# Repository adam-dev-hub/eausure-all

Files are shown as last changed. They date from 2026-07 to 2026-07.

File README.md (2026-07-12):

<div align="center">

Logo officiel EauSûre

<br/>







</div>

# EauSûre
Écosystème IoT de surveillance intelligente de la qualité de l'eau s'articule autour de trois composantes principales : une bouée connectée flottante chargée de la collecte des données, une passerelle LoRa développée en interne (DIY) assurant la transmission des mesures, ainsi qu'un environnement logiciel hétérogène regroupant des interfaces utilisateur, des API et une plateforme cloud pour le traitement, le stockage et la visualisation des données.

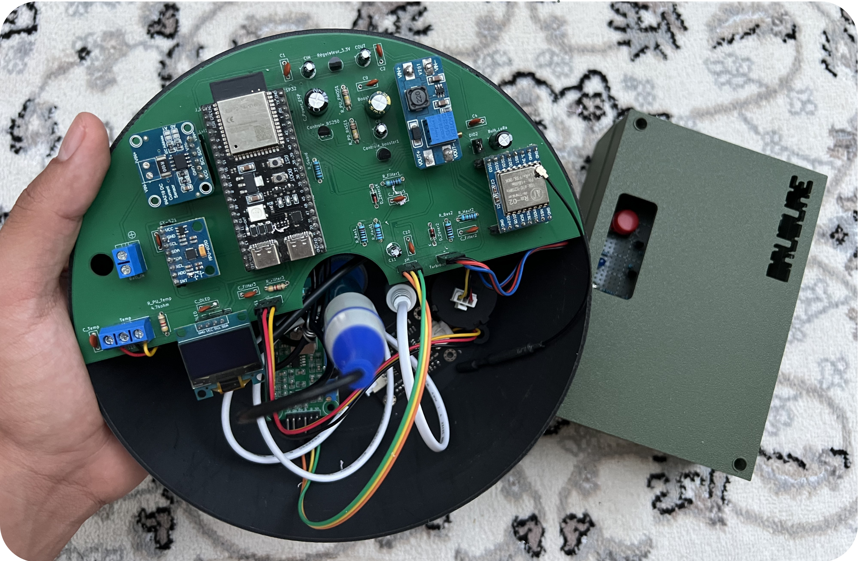
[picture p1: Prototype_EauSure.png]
Image Prototype EauSure


L'organisation regroupe les différents sous-systèmes de la solution :
- firmware embarqué du nœud de mesure et de la passerelle ;
- APIs fragmentées par responsabilité métier ;
- application mobile terrain ;
- interface web d'administration ;
- conception électronique, mécanique et modélisation système ;
- documentation technique et rapport d'ingénierie.

## Portée

EauSûre est conçu comme une plateforme complète, allant du matériel embarqué jusqu'aux interfaces de supervision.

- **Nœud de mesure** : acquisition des paramètres de qualité de l'eau, détection d'événements et communication LoRa sécurisée ;
- **Passerelle IoT** : jonction entre le terrain, le cloud, MQTT et les applications clientes ;
- **Backend fragmenté** : authentification, profil, administration, télémétrie et orchestration matérielle ;
- **Applications clientes** : usage mobile sur le terrain et supervision administrateur sur le web ;
- **Conception système** : SysML, PCB, modélisation 3D et documentation de projet.

## Dépôts principaux

- `EauSure_Firmware` : firmware du nœud de mesure et de la passerelle ;
- `EauSure_User_MobileApp` : application mobile terrain ;
- `EauSure_Admin_Dashboard_Website` : portail web d'administration ;
- `EauSure_Hardware_API` : orchestration matérielle et télémétrie ;
- `EauSure_Admin_API` : administration, pré-enregistrement et releases firmware ;
- `EauSure_Auth_API` : authentification et identité ;
- `EauSure_Profile_API` : profil utilisateur ;
- `EauSure_PCB` : conception électronique ;
- `EauSure_3D` : conception mécanique.

## Rapport

- PDF du rapport d'ingénierie : [Consulter le rapport EauSûre](https://1drv.ms/b/c/14e06c77a7dac468/IQCNwBGUbkDMTaTTdn0Hem94AVIdE5QvMWrk3accX1DUpic?e=Vb73pf)

## Architecture

- **Terrain** : nœud de mesure + passerelle ;
- **Communication** : LoRa, BLE, Wi-Fi, MQTT, HTTPS ;
- **Cloud** : APIs spécialisées, base de données, stockage firmware ;
- **Clients** : application mobile et portail web administrateur.      

## Stack

- ESP32 / FreeRTOS
- LoRa / BLE / Wi-Fi / MQTT
- Node.js / Express / TypeScript
- Next.js / React Native / Expo
- MongoDB
- KiCad / Fusion 360 / SysML / PlantUML

## Finalité

L'objectif d'EauSûre est de proposer une chaîne cohérente de surveillance de la qualité de l'eau, couvrant :
- la mesure embarquée ;
- la communication sécurisée ;
- la supervision en temps réel ;
- la maintenance et les mises à jour distantes ;
- la traçabilité technique de bout en bout.

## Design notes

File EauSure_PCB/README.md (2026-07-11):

<div align="center">

Logo officiel EauSûre

<br/>






</div>

# EauSûre Measurement Node PCB

Travail de conception PCB du nœud de mesure de la solution EauSûre.

Ce dossier contient :
- les sources KiCad du circuit principal ;
- une version inoptimisée du schéma ;
- une version simplifiée du schéma ;
- les exports visuels du schéma et du PCB ;
- un backup de fabrication avec gerbers et perçages.

## Portée

Ce dépôt documente la carte électronique du nœud de mesure EauSûre, support matériel utilisé pour :
- acquérir les paramètres physico-chimiques de l'eau : pH, TDS, turbidité et température ;
- embarquer l'unité de calcul ESP32-S3 chargée du traitement local et de la coordination des sous-ensembles ;
- intégrer le module inertiel dédié à la détection de chute et aux événements critiques ;
- assurer l'interface avec la communication LoRa sécurisée vers la passerelle ;
- supporter les phases de provisioning, d'appairage et de maintenance distante du nœud.

## Stack

- KiCad
- schématique électronique
- routage PCB
- exports SVG, PNG et PDF
- gerbers et fichiers de perçage

## Organisation du dossier

- [source](source)
  - sources KiCad principales du projet
- [exports/schematics](exports/schematics)
  - exports du schéma complet et du schéma simplifié
- [exports/board](exports/board)
  - exports visuels du PCB
- [fabrication](fabrication)
  - backup de fabrication et gerbers

## Sources principales

- [eausure-measurement-node.kicad_pcb](source/eausure-measurement-node.kicad_pcb)
- [eausure-measurement-node.kicad_pro](source/eausure-measurement-node.kicad_pro)
- [eausure-measurement-node.kicad_prl](source/eausure-measurement-node.kicad_prl)
- [eausure-measurement-node-full.kicad_sch](source/eausure-measurement-node-full.kicad_sch)
- [eausure-measurement-node-simplified.kicad_sch](source/eausure-measurement-node-simplified.kicad_sch)

## Variantes du schéma

- **Version inoptimisée** : schéma utilisé lors de la fabrication du pcb du nœud de mesure chez JLCPCB China.
- **Version simplifiée** : version la plus récente du schéma avec lisibilité ameliorée 

## Rôle du nœud de mesure dans EauSûre

Le nœud de mesure constitue le cœur embarqué de la bouée intelligente EauSûre.

Il assure notamment :
- l'acquisition périodique des mesures de qualité de l'eau ;
- le traitement local et la préparation des données avant transmission ;
- la détection de secousses anormales via le MPU6050 ;
- la communication LoRa point-à-point chiffrée avec la passerelle ;
- l'exécution de commandes distantes ;
- l'intégration dans les cycles de provisioning, d'appairage sécurisé et de mise à jour firmware.

## Aperçu du PCB

<div align="center">
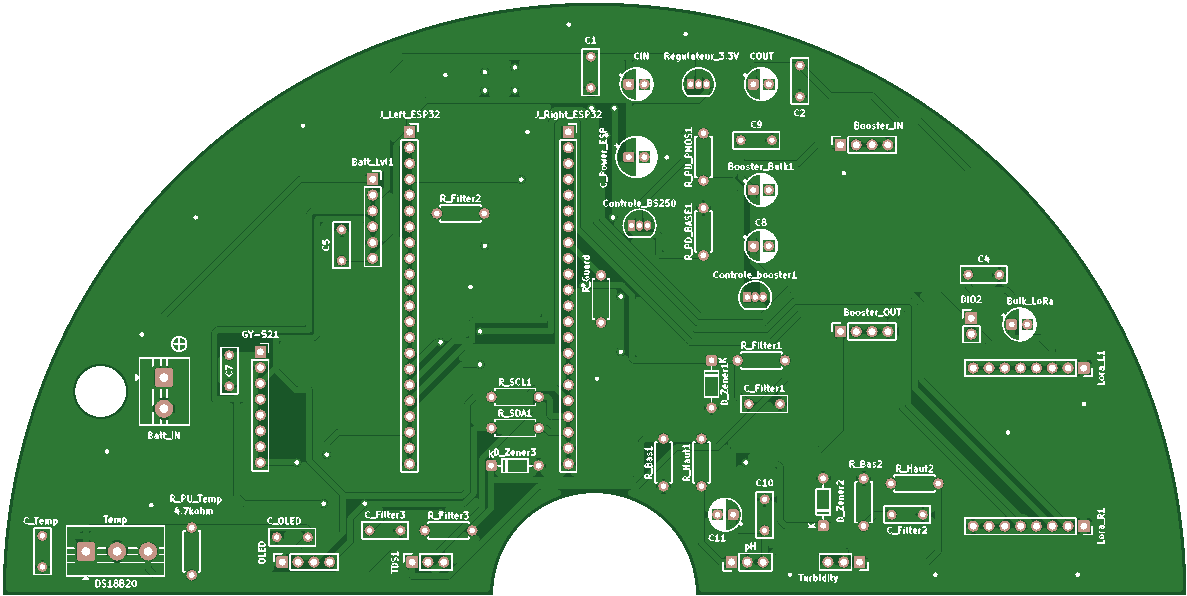
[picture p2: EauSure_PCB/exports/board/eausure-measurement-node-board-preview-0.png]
Aperçu du PCB du nœud de mesure EauSûre
  
</div>

## Fichiers de fabrication

Le dossier [fabrication](/home/adamdev/Bureau/Projet_pfe_eausure/PCB/fabrication) contient :
- les couches cuivre ;
- les masques ;
- les silkscreens ;
- les fichiers de perçage ;
- le fichier `gbrjob` ;

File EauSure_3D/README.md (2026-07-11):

<div align="center">

Logo officiel EauSûre

<br/>






</div>

# EauSûre Buoy & Gateway 3D Design

Travail de modélisation 3D de l'enveloppe mécanique de la bouée et la passerelle EauSûre.

Ce dossier contient les deux demi-coques principales du boîtier :
- la partie supérieure de la bouée ;
- la partie inférieure de la bouée ;
- la partie supérieure de la passerelle;
- la partie inférieure de la passerelle ;
- leurs sources de travail ;
- leurs exports d'impression ;
- leurs aperçus visuels.

## Portée

Le travail 3D complète la conception électronique et embarquée de la solution EauSûre.

Il couvre :
- la coque supérieure de la bouée ;
- la coque inférieure de la bouée ;
- la coque supérieure de la passerelle ;
- la coque inférieure de la passerelle ;
- la préparation des pièces pour impression ou prototypage ;
- les rendus de prévisualisation des pièces mécaniques.

## Stack

- Autodesk Fusion 360
- fichiers `3mf`
- exports `stl`
- aperçus `png`

## Organisation du dossier

- [source](source)
  - sources des pièces 3D
- [exports/stl](exports/stl)
  - exports destinés à l'impression ou à la fabrication
- [exports/previews](exports/previews)
  - aperçus visuels des pièces

## Pièces principales

**IoT Node (Buoy) :**
- [eausure-buoy-upper-shell.3mf](IoT_Node/source/eausure-buoy-upper-shell.3mf)
- [eausure-buoy-lower-shell.3mf](IoT_Node/source/eausure-buoy-lower-shell.3mf)

**Gateway Node :**
- [gateway-up-shell.stl](Gateway_Node/stl/gateway_up_shell.stl)
- [gateway-low-shell.stl](Gateway_Node/stl/gateway_low_shell.stl)

## Exports STL

**IoT Node (Buoy) :**
- [eausure-buoy-upper-shell.stl](IoT_Node/exports/stl/eausure-buoy-upper-shell.stl)
- [eausure-buoy-lower-shell.stl](IoT_Node/exports/stl/eausure-buoy-lower-shell.stl)

**Gateway Node :**
- [gateway-up-shell.stl](Gateway_Node/stl/gateway_up_shell.stl)
- [gateway-low-shell.stl](Gateway_Node/stl/gateway_low_shell.stl)

## Aperçus

**IoT Node (Buoy) :**
- [eausure-buoy-upper-shell.png](IoT_Node/exports/previews/eausure-buoy-up-shell.png)
- [eausure-buoy-lower-shell.png](IoT_Node/exports/previews/eausure-buoy-low-shell.png)

**Gateway Node :**
- [gateway-shell.png](Gateway_Node/preview/gateway_shell.png)

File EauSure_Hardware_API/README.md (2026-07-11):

<div align="center">

Logo officiel EauSûre

<br/>







</div>

# EauSûre Hardware API

API centrale de communication terrain pour l'écosystème EauSûre.

Elle est consommée par :
- `Application_Web` pour la supervision, la télémétrie, les gateways et les nœuds ;
- `Application_Mobile` pour la télémétrie, le pairing, la configuration et le provisioning ;
- `Application_Admin_API` pour le pré-enregistrement matériel ;
- `MyFreeRTOSProject` côté firmware gateway et node pour le provisioning, le pairing, les heartbeats, la télémétrie et les commandes.

## Portée

L'écosystème backend d'EauSûre repose sur une fragmentation fonctionnelle des APIs. Chaque service couvre un périmètre précis, mais l'ensemble fonctionne de manière complémentaire :
- **Hardware API** : provisioning, pairing, commandes, télémétrie et orchestration gateway/node ;
- **Admin API** : administration, pré-enregistrement et gestion des releases firmware ;
- **Auth API** : authentification, identité, jetons d'accès et OAuth ;
- **Profile API** : profil utilisateur et préférences.

Dans cette architecture, `Hardware_API` concentre la logique d'échange avec le matériel :
- **ingestion télémétrique** ;
- **provisioning gateway** ;
- **pairing node** ;
- **configuration et commandes MQTT** ;
- **état runtime des gateways et nœuds** ;
- **intégration firmware OTA/FUOTA côté commandes**.

## Vue d'ensemble

```text
                           +----------------------+
                           |   Web / Mobile App   |
                           |  JWT-authenticated   |
                           +----------+-----------+
                                      |
                                      | manage gateways, nodes,
                                      | confirm pairing
                                      v
+-------------+               +-------+--------+               +------------------+
|  IoT Node   | <-- LoRa ---> |      Gateway   | <-- HTTPS --> |       API        |
|  ESP32-S3   | <- Wifi AP -> |      ESP32     |               |  Express + TS    |
+------+------+               +---+---------+--+               +-----+--------+---+
       |                          |         |                        |        |
       | local AP during pairing  |         | MQTT commands/events   |        |
       | /identity                |         +----------------------->|        |
       | /prove                   |         |<-----------------------+        |
       | /provision               |                                           |
       |                          | telemetry/Status transmission             |
       |During Pairing Phase Only +------------------------------------------>|
       +--------------------------+------------------------------------------>|
                                                                              |
                                                               +-----------------------------+
                                                               |                             |              
                                                     +---------V---------+         +---------V---------+
                                                     |      MongoDB      |         |    MQTT Broker    |
                                                     | telemetry, nodes, |         | live data + cmds  |
                                                     | gateways, pairing |         +-------------------+
                                                     | sessions, command |
                                                     +-------------------+
```               

```text
Provisioning / Pairing
----------------------
Admin Web/App -> API: pre-register gateway and node
Gateway -> API: provision gateway to user account
Gateway -> API: confirm candidate / verify node proof
Node -> API: finalize pair-node
API -> Gateway: publish PAIRING_KEY_READY

Runtime
-------
Gateway -> Node: ACTIVATE / HEARTBEAT_REQ / MEASURE_REQ
Node -> Gateway: encrypted DATA / HEARTBEAT_ACK / ACTIVATE_OK
Gateway -> API: POST /api/sensor-data
API -> MongoDB: persist reading
API -> MQTT: publish live update
```

## Stack

- Node.js + Express
- TypeScript
- MongoDB + Mongoose
- MQTT
- JWT côté routes utilisateur
- API key côté firmware gateway

## Rôle de l'API

- reçoit les données capteurs transmises par la gateway via HTTP
- stocke la télémétrie, les signaux radio et les événements dans MongoDB
- publie la télémétrie temps réel sur MQTT pour les dashboards et les clients
- provisionne les gateways sur les comptes utilisateurs
- gère les sessions de pairing des nœuds et l'échange des clés de pairing
- expose des routes authentifiées pour la gestion des gateways et des nœuds

## Consommation de l'API

### Depuis `Application_Web`

Les pages web appellent réellement :
- `GET /api/sensor-data`
- `GET /api/sensor-data/latest`
- `GET /api/sensor-data/stats`
- `GET /api/gateways`
- `GET /api/gateways/:gatewayId/status`
- `GET /api/gateways/:gatewayId/nodes`
- `POST /api/gateways/:gatewayId/nodes/:nodeId/measure`

Le dépôt web contient aussi des routes proxy Next.js pour :
- `PUT /api/gateways/:gatewayId/config`
- `DELETE /api/gateways/:gatewayId`
- `POST /api/gateways/:gatewayId/pairing/confirm-candidate`
- `DELETE /api/gateways/:gatewayId/nodes/:nodeId`
- `PUT /api/gateways/:gatewayId/nodes/:nodeId/config`
- `POST /api/gateways/:gatewayId/firmware-update`
- `POST /api/gateways/:gatewayId/nodes/:nodeId/firmware-update`

À ce stade, je n'ai pas retrouvé d'appel direct depuis une page React vers ces proxies. Pour le web, la gestion des releases FUOTA passe surtout par `Application_Admin_API`, tandis que les commandes de déploiement matériel sont surtout consommées côté mobile.

### Depuis `Application_Mobile`

Le code consomme notamment :
- `GET /sensor-data`
- `GET /sensor-data/latest`
- `GET /sensor-data/stats`
- `GET /gateways`
- `GET /gateways/:gatewayId/nodes`
- `GET /gateways/:gatewayId/commands/:commandId`
- `POST /gateways/:gatewayId/pairing/confirm-candidate`
- `GET /gateways/:gatewayId/pairing/scan`
- `GET /gateways/:gatewayId/pairing/session/:sessionId`
- `PUT /gateways/:gatewayId/location`
- `PUT /gateways/:gatewayId/nodes/:nodeId/config`
- `DELETE /gateways/:gatewayId/nodes/:nodeId`
- `POST /gateways/:gatewayId/pairing/cancel`
- `POST /gateways/:gatewayId/firmware-update`
- `POST /gateways/:gatewayId/nodes/:nodeId/firmware-update`
- `POST /gateways/provisioning/session`

### Depuis `Application_Admin_API`

- `POST /api/registry/admin/pre-register`

### Depuis `MyFreeRTOSProject`

Le firmware consomme directement des routes de registry et de télémétrie, notamment :
- `POST /api/registry/gateway/provision`
- `POST /api/registry/pair-node/verify-proof`
- `POST /api/registry/gateway/heartbeat`
- `POST /api/registry/command/ack`
- `POST /api/registry/command/fail`
- `POST /api/registry/pair-node/rollback`
- `POST /api/registry/pair-node/fail-session`
- `GET /api/registry/gateway/:gatewayHardwareId/config`
- `POST /api/registry/gateways/:gatewayHardwareId/unprovision`
- `POST /api/registry/pair-node`
- `POST /api/sensor-data`

## Structure du projet

| Chemin | Rôle |
|---|---|
| `src/index.ts` | Application Express, middlewares, route de santé et montage des routes |
| `src/config.ts` | Configuration de l'environnement |
| `src/routes/sensorData.ts` | Ingestion télémétrique et requêtes de consultation |
| `src/routes/gateways.ts` | Routes de gestion des gateways et des nœuds côté utilisateur |
| `src/routes/registry.ts` | Provisioning gateway, pairing node, pré-enregistrement admin, acquittement de commandes et heartbeat |
| `src/services/database.ts` | Connexion MongoDB |
| `src/services/mqttService.ts` | Publication MQTT |
| `src/services/commandService.ts` | Persistance des commandes et publication MQTT des commandes |
| `src/services/pairingService.ts` | Aides pour jetons de pairing, mot de passe AP, preuve et clés AES |
| `src/models/` | Schémas MongoDB pour utilisateurs, gateways, nœuds, télémétrie, commandes et sessions de pairing |
| `api/index.ts` | Point d'entrée Vercel |

## Modèle d'authentification

Ce dépôt ne fournit pas de routes de connexion ou d'inscription utilisateur.

À la place :

- les routes côté utilisateur attendent un JWT valide dans `Authorization: Bearer <token>`
- le secret JWT doit correspondre au service d'authentification externe qui émet le jeton
- les routes côté firmware utilisent `X-Gateway-Key` ou `X-API-Key`

## Flux principaux

### Provisioning d'une gateway

1. Un administrateur pré-enregistre l'identifiant matériel de la gateway et son secret matériel.
2. La gateway envoie `POST /api/registry/gateway/provision` avec son identifiant matériel, son secret, sa version firmware et le jeton utilisateur.
3. L'API rattache la gateway au compte utilisateur et retourne le topic MQTT de commande.

### Pairing d'un nœud

1. Un administrateur pré-enregistre l'identifiant du nœud et son secret matériel.
2. L'application mobile ou web confirme un candidat de pairing détecté via `POST /api/gateways/:gatewayId/pairing/confirm-candidate`.
3. L'API crée une session de pairing et publie `CONFIRM_PAIRING` sur MQTT à destination de la gateway.
4. La gateway récupère et vérifie la preuve du nœud via `POST /api/registry/pair-node/verify-proof`.
5. Le nœud finalise le pairing via `POST /api/registry/pair-node`.
6. L'API génère et stocke la clé AES, puis publie `PAIRING_KEY_READY` vers la gateway.

### Ingestion télémétrique

1. La gateway envoie `POST /api/sensor-data`.
2. L'API résout la gateway et le nœud pairé depuis la base.
3. La lecture est stockée dans `SensorData`.
4. Un événement MQTT temps réel est publié pour les tableaux de bord et les clients.

## Résumé des routes

### Utilitaire public

| Méthode | Chemin | Notes |
|---|---|---|
| `GET` | `/health` | Vérification de santé avec état de connexion MQTT |

### Télémétrie

| Méthode | Chemin | Auth | Notes |
|---|---|---|---|
| `POST` | `/api/sensor-data` | Clé API gateway | Reçoit la télémétrie depuis la gateway |
| `GET` | `/api/sensor-data` | JWT | Télémétrie paginée pour l'utilisateur authentifié |
| `GET` | `/api/sensor-data/latest` | JWT | Dernière lecture |
| `GET` | `/api/sensor-data/stats` | JWT | Statistiques agrégées sur une fenêtre temporelle |

### Gateways et nœuds

| Méthode | Chemin | Auth | Notes |
|---|---|---|---|
| `GET` | `/api/gateways` | JWT | Liste les gateways de l'utilisateur courant |
| `DELETE` | `/api/gateways/:gatewayId` | JWT | Délie une gateway du compte utilisateur courant |
| `GET` | `/api/gateways/:gatewayId/status` | JWT | État d'une gateway |
| `GET` | `/api/gateways/:gatewayId/commands/:commandId` | JWT | Récupère l'état d'une commande |
| `PUT` | `/api/gateways/:gatewayId/config` | JWT | Met à jour la configuration gateway et publie une commande |
| `GET` | `/api/gateways/:gatewayId/nodes` | JWT | Liste les nœuds rattachés à une gateway |
| `POST` | `/api/gateways/provisioning/session` | JWT | Crée une session de provisioning pour une gateway |
| `GET` | `/api/gateways/:gatewayId/pairing/scan` | JWT | Déclenche un scan de pairing via MQTT |
| `POST` | `/api/gateways/:gatewayId/pairing/confirm-candidate` | JWT | Confirme un candidat de nœud détecté |
| `GET` | `/api/gateways/:gatewayId/pairing/session/:sessionId` | JWT | Lit l'état d'une session de pairing |
| `POST` | `/api/gateways/:gatewayId/pairing/cancel` | JWT | Annule un pairing sur la gateway |
| `PUT` | `/api/gateways/:gatewayId/location` | JWT | Met à jour la localisation de la gateway |
| `DELETE` | `/api/gateways/:gatewayId/nodes/:nodeId` | JWT | Dé-paire un nœud |
| `POST` | `/api/gateways/:gatewayId/nodes/:nodeId/measure` | JWT | Demande une mesure immédiate |
| `PUT` | `/api/gateways/:gatewayId/nodes/:nodeId/config` | JWT | Met à jour la configuration du nœud et envoie éventuellement une config LoRa |
| `POST` | `/api/gateways/:gatewayId/firmware-update` | JWT | Met en file une mise à jour firmware de gateway |
| `POST` | `/api/gateways/:gatewayId/nodes/:nodeId/firmware-update` | JWT | Met en file une mise à jour firmware de nœud |

### Registry et intégration firmware

| Méthode | Chemin | Auth | Notes |
|---|---|---|---|
| `POST` | `/api/registry/admin/pre-register` | JWT admin | Pré-enregistre une gateway ou un nœud avec son secret matériel |
| `POST` | `/api/registry/gateway/provision` | Jeton + secret matériel | Rattache une gateway à un compte utilisateur |
| `POST` | `/api/registry/gateway/heartbeat` | Clé API gateway | Met à jour l'état de la gateway et récupère les commandes en attente |
| `GET` | `/api/registry/gateway/:gatewayHardwareId/config` | Clé API gateway | Récupère la configuration persistée de la gateway et des nœuds |
| `POST` | `/api/registry/command/ack` | Clé API gateway | Acquitte une commande |
| `POST` | `/api/registry/command/fail` | Clé API gateway | Marque une commande comme échouée |
| `POST` | `/api/registry/pair-node/verify-proof` | Clé API gateway | Vérifie la preuve du nœud et émet un jeton de pairing |
| `POST` | `/api/registry/pair-node` | Jeton de pairing | Finalise le pairing du nœud et génère la clé AES |
| `POST` | `/api/registry/pair-node/rollback` | Clé API gateway | Annule un pairing échoué |
| `POST` | `/api/registry/pair-node/fail-session` | Clé API gateway | Marque une session comme échouée avant émission du jeton |
| `POST` | `/api/registry/gateway/node-status` | Clé API gateway | Met à jour l'état actif et le signal d'un nœud |
| `POST` | `/api/registry/gateways/:gatewayHardwareId/unprovision` | Clé API gateway | Marque une gateway comme déprovisionnée |

## Exemple de requête télémétrique

```http
POST /api/sensor-data
X-Gateway-Key: your-gateway-api-key
Content-Type: application/json
```

```json
{
  "nodeId": "12345678",
  "gatewayHardwareId": "A1B2C3D4E5F6",
  "seq": 42,
  "b": 85,
  "v": 3.9,
  "m": 150,
  "p": 6.82,
  "ps": 8,
  "t": 280,
  "ts": 7,
  "u": 2.1,
  "us": 6,
  "tw": 22.5,
  "tm": 45.2,
  "te": 38.1,
  "e": "None",
  "rssi": -45,
  "snr": 11.2
}
```

## Variables d'environnement

Variables principales utilisées par `src/config.ts` :
- `NODE_ENV`
- `PORT`
- `API_BASE_URL`
- `JWT_SECRET`
- `MONGODB_URI`
- `MONGODB_CONNECT_TIMEOUT_MS`
- `MONGODB_SERVER_SELECTION_TIMEOUT_MS`
- `GATEWAY_API_KEY`
- `MQTT_BROKER_URL`
- `MQTT_PORT`
- `MQTT_USERNAME`
- `MQTT_PASSWORD`
- `MQTT_CLIENT_ID`
- `MQTT_PUBLISH_TOPIC`
- `MQTT_QOS`
- `RATE_LIMIT_WINDOW_MS`
- `RATE_LIMIT_MAX_REQUESTS`
- `CORS_ORIGIN`
- `LOG_LEVEL`

Notes :

- `JWT_SECRET` doit correspondre au service d'authentification externe qui émet les jetons utilisateur.
- `GATEWAY_API_KEY` doit correspondre à la valeur utilisée par le firmware gateway.

## Déploiement

Ce projet inclut `api/index.ts` pour le déploiement Vercel ainsi que `vercel.json` pour le routage.

## Notes

- Les commandes sont stockées dans MongoDB puis également publiées sur MQTT.
- Les sessions de pairing et les commandes utilisent une expiration TTL côté MongoDB.
- L'API attend que les gateways et les nœuds soient pré-enregistrés avant provisioning et pairing.

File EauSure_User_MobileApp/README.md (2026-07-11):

<div align="center">

Logo officiel EauSûre

<br/>







</div>

# EauSûre Mobile

Application mobile EauSûre pour l'exploitation terrain et le suivi temps réel du parc IoT.

Elle permet :
- l'authentification utilisateur ;
- le suivi des mesures d'eau en temps réel ;
- la supervision des gateways et des nœuds ;
- le provisioning BLE et Wi-Fi des passerelles ;
- l'association de nœuds ;
- la configuration matérielle ;
- les alertes locales et le suivi MQTT.

## Portée

L'écosystème EauSûre repose sur une fragmentation fonctionnelle des APIs. `Application_Mobile` s'appuie sur plusieurs services complémentaires :

- **Auth API** : connexion, identité et token d'accès ;
- **Profile API** : profil utilisateur et préférences ;
- **Admin API** : pré-enregistrement et opérations administratives ciblées ;
- **Hardware API** : provisioning, matériel, télémétrie, pairing et commandes terrain.

Dans cette architecture, `Application_Mobile` se concentre sur :
- l'expérience utilisateur mobile ;
- les workflows terrain autour du provisioning et de l'association ;
- la consommation temps réel des données MQTT ;
- la consultation et la configuration du matériel.

## Stack

- Expo 54
- React Native 0.81
- Expo Router
- Expo Secure Store
- Expo Notifications
- Expo Location
- Expo Video
- BLE avec `react-native-ble-plx`
- MQTT avec `paho-mqtt`
- visualisation mobile avec Skia et `react-native-gifted-charts`

## Écrans principaux

- onboarding
- login et register
- tableau de bord temps réel
- télémétrie détaillée
- matériel
- scan / provisioning
- paramètres utilisateur

## APIs consommées

### Authentification

L'application mobile consomme `Application_Auth_API` pour :
- `POST /auth/login`
- `POST /auth/register`
- `GET /auth/me`
- les entrées OAuth et de redirection associées

### Profil

L'application mobile consomme `Application_Profile_API` pour :
- `GET /api/me`
- `PUT /api/me`

### Matériel et télémétrie

L'application mobile consomme `Hardware_API` pour :
- `GET /api/sensor-data`
- `GET /api/sensor-data/latest`
- `GET /api/sensor-data/stats`
- `GET /api/gateways`
- `GET /api/gateways/:gatewayId/nodes`
- `GET /api/gateways/:gatewayId/commands/:commandId`
- `POST /api/gateways/provisioning/session`
- `GET /api/gateways/:gatewayId/pairing/scan`
- `GET /api/gateways/:gatewayId/pairing/session/:sessionId`
- `POST /api/gateways/:gatewayId/pairing/confirm-candidate`
- `POST /api/gateways/:gatewayId/pairing/cancel`
- `PUT /api/gateways/:gatewayId/location`
- `PUT /api/gateways/:gatewayId/nodes/:nodeId/config`
- `DELETE /api/gateways/:gatewayId/nodes/:nodeId`
- `POST /api/gateways/:gatewayId/firmware-update`
- `POST /api/gateways/:gatewayId/nodes/:nodeId/firmware-update`

## Variables d'environnement

Variables nécessaires :
- `EXPO_PUBLIC_AUTH_API_URL`
- `EXPO_PUBLIC_PROFILE_API_URL`
- `EXPO_PUBLIC_ADMIN_API_URL`
- `EXPO_PUBLIC_HARDWARE_API_URL`
- `EXPO_PUBLIC_MAPBOX_TOKEN`
- `EXPO_PUBLIC_MQTT_BROKER_URL`
- `EXPO_PUBLIC_MQTT_USERNAME`
- `EXPO_PUBLIC_MQTT_PASSWORD`
- `EXPO_PUBLIC_MQTT_TOPIC`

## Fonctionnement

### Authentification mobile

Le token utilisateur est :
- obtenu via `Application_Auth_API` ;
- stocké localement avec `Expo Secure Store` ;
- réutilisé ensuite pour les appels profil, matériel et provisioning.

### Temps réel MQTT

Le contexte `MqttContext` :
- ouvre une connexion au broker ;
- s'abonne au topic configuré ;
- reçoit les données live des nœuds ;
- alimente ensuite les vues temps réel de l'application.

### Provisioning passerelle

Le flux de scan :
- démarre une session sécurisée côté `Hardware_API` ;
- échange les informations de provisioning via BLE ;
- transmet les identifiants Wi-Fi et les secrets nécessaires ;
- laisse ensuite la passerelle finaliser son enregistrement cloud.

### Pairing et configuration

L'application mobile permet :
- de scanner les nœuds disponibles ;
- de confirmer un candidat d'association ;
- de suivre la session d'association ;
- de mettre à jour la configuration d'un nœud ;
- de déclencher certaines opérations matérielles ciblées.

### Alertes et notifications

L'application :
- demande la permission de notifications ;
- calcule les alertes locales à partir des mesures ;
- affiche des événements critiques et de supervision ;
- utilise l'icône Android déclarée dans `app.json`.

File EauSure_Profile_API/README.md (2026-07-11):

<div align="center">

Logo officiel EauSûre

<br/>






</div>

# EauSûre Profile API

API de profil et de préférences utilisateur pour l'écosystème EauSûre.

Elle est consommée par :
- `Application_Web` pour lire et mettre à jour le profil via une route proxy Next ;
- `Application_Mobile` pour charger et modifier le profil utilisateur directement.

## Portée

L'écosystème backend d'EauSûre repose sur une fragmentation fonctionnelle des APIs. Chaque service couvre un périmètre précis, mais l'ensemble fonctionne de manière complémentaire :
- **Profile API** : profil utilisateur, préférences et fusion des données `users` + `userProfiles` ;
- **Auth API** : authentification, identité, jetons d'accès et OAuth ;
- **Admin API** : administration, pré-enregistrement et gestion des releases firmware ;
- **Hardware API** : opérations techniques liées aux passerelles, nœuds et échanges terrain.

Dans cette architecture, `Application_Profile_API` se concentre sur :
- **lecture du profil enrichi** ;
- **mise à jour du profil et des préférences** ;
- **provisionnement automatique d'un profil vide si nécessaire**.

## Stack

- Express
- MongoDB avec Mongoose
- JWT pour valider le token entrant
- logging applicatif détaillé avec `LOG_LEVEL`

## Consommation de l'API

### Depuis `Application_Web`

Le code de `Application_Web` consomme :
- `GET /api/me`
- `PUT /api/me`

### Depuis `Application_Mobile`

Le code de `Application_Mobile` consomme :
- `GET /api/me`
- `PUT /api/me`

## Variables d'environnement

Variables nécessaires au fonctionnement de base :
- `MONGO_URI`
- `JWT_SECRET`
- `PORT`
- `LOG_LEVEL`

Valeurs attendues pour `LOG_LEVEL` dans le code :
- `debug`
- `info`
- `warn`
- `error`
## Fonctionnement

### Authentification

Toutes les routes sensibles exigent un header :

```http
Authorization: Bearer <token>
```

Le middleware accepte plusieurs identifiants possibles dans le payload JWT :
- `email`
- `id`
- `userId`
- `sub`

Le champ résolu est stocké dans `req.userIdentifier`.

### Route `/api/me`

`GET /api/me` :
- résout d'abord l'utilisateur dans la collection `users` ;
- tente la recherche par email ;
- bascule sur `_id` si nécessaire ;
- charge ensuite le document `userProfiles` ;
- crée un profil vide si absent ;
- retourne une vue fusionnée entre `users` et `userProfiles`.

`PUT /api/me` :
- met à jour certains champs de `users` ;
- met à jour les préférences et le fuseau dans `userProfiles` ;
- retourne ensuite une réponse fusionnée.

Champs utilisateur pris en charge :
- `name`
- `avatar`
- `image`
- `organization`
- `phone`

Préférences prises en charge :
- `preferences.theme`
- `preferences.language`
- `preferences.notifications.*`
- `preferences.units.*`
- `preferences.security.*`
- `timezone`

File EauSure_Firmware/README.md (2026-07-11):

<div align="center">

Logo officiel EauSûre

<br/>







</div>

# EauSûre Firmware

Firmware embarqué des deux composants physiques principaux de la solution EauSûre :
- `IoT_Node/` : nœud de mesure ESP32-S3 ;
- `Gateway_Node/` : passerelle ESP32.

Ce dépôt couvre la logique embarquée de mesure, de communication radio sécurisée, de provisioning, d'appairage, de supervision et de mise à jour firmware.

## Portée

Dans l'architecture EauSûre :
- le **nœud de mesure** acquiert les données de qualité d'eau, détecte les événements critiques et dialogue avec la passerelle en LoRa chiffré ;
- la **passerelle** assure la connectivité Wi-Fi, les échanges API/MQTT, le provisioning BLE, l'appairage des nœuds, la télémétrie cloud et l'orchestration des campagnes OTA/FUOTA.

Le firmware s'inscrit donc au cœur du système embarqué, entre le matériel terrain et la plateforme cloud.

## Stack

- Arduino / ESP32
- FreeRTOS
- LoRa point-à-point sécurisé
- BLE pour le provisioning passerelle
- Wi-Fi local pour l'appairage du nœud
- MQTT pour les commandes et retours temps réel
- HTTPS / API backend pour provisioning, heartbeat et télémétrie
- FUOTA pour les mises à jour du nœud

## Organisation du dépôt

- [IoT_Node](IoT_Node)
  - firmware du nœud de mesure ESP32-S3
- [Gateway_Node](Gateway_Node)
  - firmware de la passerelle ESP32

## IoT Node

Le nœud de mesure est responsable de :
- lire pH, TDS, turbidité, température, batterie et données inertielles ;
- détecter les événements de type `SHAKE` ;
- afficher l'état local sur OLED et RGB ;
- répondre aux commandes passerelle ;
- exposer un point d'accès Wi-Fi temporaire pendant l'appairage initial ;
- recevoir et appliquer des mises à jour FUOTA.

Fichiers clés :
- `IoT_Node.ino`
- `app_state.*`
- `pairing_mode.*`
- `pairing_store.*`
- `lora_radio.*`
- `task_sensors.*`
- `task_control.*`
- `task_mpu.*`
- `task_display.*`
- `display_oled.*`
- `firmware_version.*`

## Gateway Node

La passerelle est responsable de :
- recevoir les credentials Wi-Fi via BLE ;
- provisionner la passerelle côté cloud ;
- découvrir et appairer les nœuds voisins ;
- transmettre les commandes LoRa ;
- recevoir, valider et router les charges utiles chiffrées ;
- synchroniser les commandes MQTT ;
- pousser les données vers le backend ;
- déclencher les alertes locales ;
- orchestrer OTA passerelle et FUOTA nœud.

Fichiers clés :
- `Gateway_Node.ino`
- `normal_mode.*`
- `provisioning_mode.*`
- `ble_provisioning.*`
- `wifi_store.*`
- `node_pairing_mode.*`
- `node_pairing_store.*`
- `mqtt_gateway.*`
- `api_client.*`
- `wifi_manager.*`
- `lora_radio.*`
- `fuota_manager.*`
- `fuota_job_store.*`
- `telemetry.*`
- `audio_alert.*`
- `sd_logger.*`

## Protocole LoRa actuel

Les types de trames actuellement définis entre passerelle et nœud sont :

| Type | Direction | Signification |
|---|---|---|
| `0x01` | Node -> Gateway | `DATA` (`MEASURE_RESP` ou `SHAKE_ALERT`) |
| `0x02` | Both | `ACK` |
| `0x03` | Gateway -> Node | `MEASURE_REQ` |
| `0x04` | Gateway -> Node | `HEARTBEAT_REQ` |
| `0x05` | Node -> Gateway | `HEARTBEAT_ACK` |
| `0x06` | Gateway -> Node | `ACTIVATE` |
| `0x07` | Node -> Gateway | `ACTIVATE_OK` |
| `0x08` | Gateway -> Node | `SET_CONFIG` |
| `0x09` | Gateway -> Node | `UNPAIR` |
| `0x0A` | Gateway -> Node | `SLEEP` |
| `0x0B` | Gateway -> Node | `FUOTA_BEGIN` |
| `0x0C` | Gateway -> Node | `FUOTA_CHUNK` |
| `0x0D` | Gateway -> Node | `FUOTA_END` |
| `0x0E` | Gateway -> Node | `FUOTA_COMMIT` |

Caractéristiques du protocole :
- chiffrement authentifié `AES-128-GCM`
- validation `CRC-16`
- protection anti-rejeu par compteur de séquence
- évitement de collision basé sur `CAD`

### Structure détaillée de la trame LoRa

Pour garantir la sécurité, la fiabilité et la conformité aux contraintes de la bande ISM (fréquence **433 MHz**), chaque trame du protocole EauSûre suit une structure binaire rigoureuse d'une taille maximale de **222 octets** :

*   **En-tête (Header) en clair (24 octets) :** Contient les informations indispensables au routage et à la validation : version du protocole, type de message (`MsgType`), identifiant du dispositif (`Device ID`), numéro de séquence anti-rejeu (`seq`), nonce de chiffrement et taille de la charge utile.
    *   *Sécurité (AAD) :* L'en-tête voyage non chiffré pour permettre un traitement rapide, mais il est intégré au calcul du tag AES-GCM en tant que **Données Authentifiées Supplémentaires (AAD)**. Toute altération en transit invalidera le tag et provoquera le rejet de la trame.
*   **Payload chiffré (0 à 180 octets) :** Contient les données applicatives (mesures de qualité d'eau, configurations, chunks de FUOTA), chiffrées de bout en bout en **AES-128-GCM**.
*   **Tag GCM (16 octets) :** Le tag d'authentification cryptographique garantissant l'intégrité absolue et l'authenticité de la trame.
*   **CRC-16 Logiciel (2 octets) :** Calculé par le firmware de l'émetteur et vérifié par le récepteur, offrant un second niveau d'intégrité de bout en bout en plus du CRC matériel du transceiver radio **SX1278**.

<div align="center">
  Structure détaillée de la trame LoRa EauSûre
</div>

## Provisioning et appairage

Pour passer d'un état initial "sortie d'usine" à un fonctionnement nominal sécurisé, le système EauSûre met en œuvre un cycle de vie rigoureux divisé en trois phases principales (illustrées par le diagramme ci-dessous) :

### 1. Mise en service de la passerelle (BLE Provisioning)
Lorsque la passerelle démarre pour la première fois et qu'aucun identifiant Wi-Fi n'est enregistré en mémoire non volatile (NVS) :
1.  **Mode Provisioning :** La passerelle active son interface Bluetooth Low Energy (BLE) et diffuse son identifiant accompagnée d'un challenge à usage unique (anti-rejeu).
2.  **Transmission cryptée :** L'application mobile récupère le secret de la passerelle depuis le cloud, dérive une clé de chiffrement et une clé de signature via **HMAC-SHA256**, puis envoie de façon sécurisée les identifiants Wi-Fi et le jeton d'authentification utilisateur.
3.  **Connexion & Sauvegarde :** La passerelle déchiffre les paramètres, valide le challenge, teste la connexion Wi-Fi et sauvegarde les credentials. Elle libère ensuite entièrement la pile BLE en RAM pour libérer de la mémoire vive pour la suite.

### 2. Appairage du nœud de mesure (Wi-Fi Local Pairing)
Une fois la passerelle connectée à Internet, elle doit s'associer avec le nœud de mesure local :
1.  **Point d'accès temporaire :** Le nœud démarre en mode **SoftAP** et crée un réseau Wi-Fi local nommé `IOT-<NODE_ID>`, protégé par une clé dérivée de son secret matériel unique.
2.  **Scan & Connexion :** La passerelle scanne l'environnement, se connecte au SoftAP du nœud grâce à la clé d'appairage récupérée via MQTT, puis interroge le nœud (routes `/identity` et `/prove`).
3.  **Preuve Cryptographique :** Le nœud génère une preuve de légitimité signée par HMAC-SHA256 que la passerelle transmet au backend pour validation.
4.  **Échange de clés :** Une fois validé par le cloud, un jeton cryptographique temporaire est transmis au nœud (via `/provision`), lui ordonnant de rejoindre le réseau Wi-Fi local en mode **STA** (Station).
5.  **Clé AES définitive :** Le nœud (via HTTPS) et la passerelle (via MQTT) récupèrent auprès du cloud la **clé AES de session LoRa définitive** qu'ils enregistrent localement en flash.

### 3. Transition vers le Mode Normal
Pour assurer la stabilité et une faible consommation :
*   Le nœud détruit sa tâche serveur HTTP locale, coupe le Wi-Fi local et bascule sur le protocole radio **LoRa chiffré**. Il passe la majorité de son temps en veille profonde (Deep Sleep).
*   La passerelle désactive toutes les tâches d'appairage temporaires et alloue ses ressources aux connexions **MQTT(S)** sécurisées et au traitement audio local.

Le flux complet des transitions d'états et le cycle de vie du système sont représentés dans le schéma ci-dessous :

<div align="center">
  Flux de transition des modes de fonctionnement
</div>

## Runtime nominal

En fonctionnement nominal :
- la passerelle réactive le nœud via `ACTIVATE` ;
- elle pilote les fenêtres de réveil avec `MEASURE_REQ`, `HEARTBEAT_REQ` et `SLEEP` ;
- le nœud répond avec des trames `DATA` ou `HEARTBEAT_ACK` ;
- la passerelle relaie ensuite les mesures vers le cloud et MQTT ;
- en cas de `SHAKE`, une fenêtre de suivi spécifique est ouverte.

## FUOTA 

Le firmware supporte désormais :
- le téléchargement de firmware côté passerelle ;
- la persistance d'un job FUOTA entre redémarrages ;
- le transfert LoRa fragmenté vers le nœud ;
- le commit différé du nouveau firmware ;
- le reporting d'état vers MQTT / backend.

## Configuration

Créer `config.h` à partir des templates :
- `IoT_Node/config.h.template`
- `Gateway_Node/config.h.template`

## Compilation

- `IoT_Node/` cible une carte `ESP32-S3`
- `Gateway_Node/` cible une passerelle `ESP32`
- ouvrir chaque `.ino` dans Arduino IDE ou PlatformIO avec les bibliothèques requises

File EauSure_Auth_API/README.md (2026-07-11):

<div align="center">

Logo officiel EauSûre

<br/>







</div>

# EauSûre Auth API

API d'authentification et d'identité pour l'écosystème EauSûre.

Elle est consommée par :
- `Application_Web` pour l'authentification via NextAuth ;
- `Application_Mobile` pour la connexion locale, l'inscription, la restauration de session et les entrées OAuth.

## Portée

L'écosystème backend d'EauSûre repose sur une fragmentation fonctionnelle des APIs. Chaque service couvre un périmètre précis, mais l'ensemble fonctionne de manière complémentaire :
- **Auth API** : authentification, identité, jetons d'accès et OAuth ;
- **Profile API** : données de profil et informations utilisateur ;
- **Admin API** : administration, pré-enregistrement et gestion des releases firmware ;
- **Hardware API** : opérations techniques liées aux passerelles, nœuds et échanges terrain.

Dans cette architecture, `Application_Auth_API` se concentre sur son rôle d'identité :
- **Connexion locale** : vérification email/mot de passe et émission du JWT ;
- **Inscription locale** : création de compte utilisateur ;
- **OAuth** : Google et GitHub, en mode login ou register ;
- **Hydratation de session** : récupération du profil à partir du token ;
- **Provisioning token** : génération d'un jeton court pour le provisioning matériel.

## Stack

- Express
- MongoDB avec Mongoose
- JWT pour les jetons d'accès
- Passport pour OAuth Google et GitHub
- bcryptjs pour le hash des mots de passe

## Consommation de l'API

### Depuis `Application_Web`

Le code de `Application_Web` consomme directement :
- `POST /api/auth/login`
- `GET /api/auth/me`

### Depuis `Application_Mobile`

Le code de `Application_Mobile` consomme directement :
- `POST /api/auth/login`
- `POST /api/auth/register`
- `GET /api/auth/me`
- `GET /api/auth/google`
- `GET /api/auth/google/register`
- `GET /api/auth/github`
- `GET /api/auth/github/register`

## Routes exposées

- `POST /api/auth/login`
- `POST /api/auth/register`
- `GET /api/auth/google`
- `GET /api/auth/google/callback`
- `GET /api/auth/google/register`
- `GET /api/auth/google/register/callback`
- `GET /api/auth/github`
- `GET /api/auth/github/register`
- `GET /api/auth/github/callback`
- `GET /api/auth/me`
- `POST /api/auth/provisioning-token`
- `GET /`

## Variables d'environnement

Variables nécessaires au fonctionnement de base :
- `MONGO_URI`
- `JWT_SECRET`
- `PORT`

Variables utilisées pour OAuth et les redirections :
- `API_URL`
- `FRONTEND_URL`
- `GOOGLE_CLIENT_ID`
- `GOOGLE_CLIENT_SECRET`
- `GITHUB_CLIENT_ID`
- `GITHUB_CLIENT_SECRET`

## Fonctionnement

### Connexion locale

`POST /api/auth/login` :
- cherche l'utilisateur par email ;
- vérifie le mot de passe avec `bcryptjs` ;
- met à jour `lastLogin` ;
- retourne un JWT valable `7d`.

### Inscription locale

`POST /api/auth/register` :
- vérifie que l'email n'existe pas déjà ;
- hash le mot de passe ;
- crée un utilisateur local ;
- retourne un succès simple sans token immédiat.

### OAuth

Les stratégies Google et GitHub sont activées seulement si les variables d'environnement correspondantes sont présentes.

Le code distingue deux intentions :
- **login**
- **register**

Pour GitHub, une seule callback est utilisée et le mode est distingué via `state`.

### Hydratation de session

`GET /api/auth/me` :
- exige un header `Authorization: Bearer <token>` ;
- vérifie le JWT ;
- retourne l'utilisateur sans le champ `password`.

### Provisioning token

`POST /api/auth/provisioning-token` :
- exige un utilisateur authentifié ;
- valide `gatewayHardwareId` ;
- génère un JWT court de type `gateway_provisioning` ;
- retourne le token avec `expiresIn`.

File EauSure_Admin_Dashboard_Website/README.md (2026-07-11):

<div align="center">

Logo officiel EauSûre

<br/>







</div>

# EauSûre Web Admin

Interface web d'administration de l'écosystème EauSûre.

Elle centralise les usages administrateur de la plateforme :
- authentification des administrateurs ;
- supervision du parc passerelles et nœuds ;
- consultation des métriques et statistiques d'évaluation d'efficacité ;
- gestion des utilisateurs ;
- pré-enregistrement du matériel ;
- gestion des releases firmware ;
- consultation de la documentation et des issues GitHub.

## Portée

L'écosystème EauSûre repose sur une fragmentation fonctionnelle des APIs. `Application_Web` n'embarque pas toute la logique métier : elle orchestre plusieurs services spécialisés via des routes proxy Next.js.

- **Auth API** : connexion administrateur et validation d'identité ;
- **Profile API** : lecture et mise à jour du profil administrateur ;
- **Admin API** : gestion des utilisateurs, pré-enregistrement et releases FUOTA ;
- **Hardware API** : supervision des gateways, nœuds, mesures et statistiques ;
- **GitHub API** : consultation des dépôts, fichiers de documentation et tickets techniques.

Dans cette architecture, `Application_Web` se concentre sur :
- l'expérience d'administration ;
- la composition des données issues des APIs ;
- la protection d'accès côté serveur ;
- la présentation des vues de diagnostic, supervision et déploiement.

## Stack

- Next.js 16 avec App Router
- React 19
- TypeScript
- Tailwind CSS
- NextAuth pour la session administrateur
- MongoDB pour les données locales web
- MQTT côté client pour le flux live
- intégration GitHub pour la documentation et les issues

## Écrans principaux

- `/fr/admin/signin`
- `/fr/admin`
- `/fr/admin/supervise-system`
- `/fr/admin/manage-users`
- `/fr/admin/pre-register`
- `/fr/admin/deploy-updates`
- `/fr/admin/diagnose-problems`

## APIs consommées

### Authentification

Le web admin s'appuie sur `Application_Auth_API` pour :
- `POST /auth/login`
- `GET /auth/me`

### Profil

Le web admin consomme `Application_Profile_API` via sa route proxy locale :
- `GET /api/user/me`
- `PATCH /api/user/me`

### Administration

Le web admin consomme `Application_Admin_API` pour :
- `GET /api/users`
- `PATCH /api/users/:id`
- `GET /api/provisioning/pre-register`
- `POST /api/provisioning/pre-register`
- `GET /api/fuota/releases`
- `POST /api/fuota/releases/inspect`
- `POST /api/fuota/releases/upload`

### Matériel et télémétrie

Le web admin consomme `Hardware_API` pour :
- `GET /api/sensor-data`
- `GET /api/sensor-data/latest`
- `GET /api/sensor-data/stats`
- `GET /api/gateways`
- `GET /api/gateways/:gatewayId/nodes`
- `POST /api/gateways/:gatewayId/nodes/:nodeId/measure`

### Diagnostic GitHub

Le web admin interroge l'API GitHub pour :
- lister les dépôts ;
- lire des fichiers de documentation ;
- lister, créer et commenter des issues.

## Variables d'environnement

Variables nécessaires au fonctionnement de base :
- `MONGODB_URI`
- `MONGODB_DB`
- `NEXTAUTH_URL`
- `NEXTAUTH_SECRET`
- `AUTH_API_URL` 
- `PROFILE_API_URL` 
- `HARDWARE_API_URL`
- `GITHUB_TOKEN`
- `GITHUB_ORG`
- `MAIL_PROVIDER`
- `MAIL_FROM`
- `NEXT_PUBLIC_MAPBOX_TOKEN`
- `NEXT_PUBLIC_MQTT_BROKER_URL`
- `NEXT_PUBLIC_MQTT_TOPIC`

## Fonctionnement

### Authentification administrateur

L'authentification passe par NextAuth avec un provider `Credentials`.

Au login :
- le web appelle `Application_Auth_API` ;
- récupère un `accessToken` ;
- vérifie que le rôle retourné est bien `admin` ;
- stocke ensuite une session JWT côté web.

### Supervision matérielle

Les pages d'administration interrogent les routes proxy locales `/api/eausure/*`.

Ces routes :
- récupèrent la session administrateur ;
- transmettent le bearer token à `Hardware_API` ;
- normalisent les erreurs avant retour à l'UI.

### Gestion d'utilisateurs et FUOTA

Les pages `manage-users`, `pre-register` et `deploy-updates` passent par les routes proxy locales `/api/admin/*`.

Cette couche :
- protège l'accès côté serveur ;
- relaie les appels à `Application_Admin_API` ;
- évite d'exposer directement les URLs backend à l'interface.

### Diagnostic et documentation

La page `diagnose-problems` s'appuie sur des routes `/api/github/*` pour :
- parcourir des dépôts ;
- lire des fichiers Markdown ;
- suivre les issues techniques.

### Réinitialisation de mot de passe

Le web expose :
- `POST /api/auth/forgot-password`
- `POST /api/auth/reset-password`

La demande crée un jeton temporaire en base, puis envoie un email via `Resend` ou `Brevo` selon la configuration.

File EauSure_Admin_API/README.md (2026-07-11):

<div align="center">

Logo officiel EauSûre

<br/>






</div>

# EauSûre Admin API

API minimale d'administration pour EauSure.

Elle expose ces routes utilisées par `Application_Web` pour :
- gérer les utilisateurs ;
- pré-enregistrer les équipements ;
- inspecter, publier et lister les releases firmware.

## Portée

L'écosystème backend d'EauSûre repose sur une **fragmentation fonctionnelle des APIs**. Chaque service couvre un périmètre précis, mais l'ensemble fonctionne de manière complémentaire :
- **Admin API** : administration, pré-enregistrement et gestion des releases firmware ;
- **Hardware API** : opérations techniques liées aux passerelles, nœuds et échanges terrain ;
- **Profile API** : données de profil et informations liées aux utilisateurs ;
- **Auth API** : authentification, identité et sécurité d'accès.

Dans cette architecture, `Application_Admin_API` n'a pas vocation à centraliser toute la logique métier. Elle se concentre sur son rôle d'administration :
- **Utilisateurs** : liste, filtres, mise à jour et note administrateur ;
- **Pré-enregistrement matériel** : passerelles et nœuds avant déploiement ;
- **Firmware** : inspection et versionning de l'inventaire `.bin` et publication des releases.

## Stack

- Express
- MongoDB avec Mongoose sur VM AZUR
- JWT pour l'authentification
- Vercel Blob pour le stockage des binaires
- appel vers `Hardware_API` pour le pré-enregistrement

## Routes exposées

- `GET /api/users`
- `PATCH /api/users/:id`
- `POST /api/provisioning/pre-register`
- `GET /api/provisioning/pre-register`
- `GET /api/fuota/releases`
- `POST /api/fuota/releases/inspect`
- `POST /api/fuota/releases/upload`

## Variables d'environnement

- `MONGO_URI`
- `JWT_SECRET`
- `PORT`
- `CORS_ORIGIN`
- `HARDWARE_API_URL`

## Fonctionnement

### Utilisateurs

`GET /api/users` supporte la pagination et les filtres `role`, `status` et `search`.

`PATCH /api/users/:id` permet de modifier :
- `role`
- `status`
- `adminNotes`

### Pré-enregistrement

`POST /api/provisioning/pre-register` :
- valide `kind` (`gateway` ou `node`) ;
- vérifie la longueur du `deviceSecret` ;
- stocke un hash SHA-256 du secret ;
- transmet ensuite la demande à `Hardware_API`.

### Firmware

`POST /api/fuota/releases/inspect` :
- lit le binaire ;
- tente de détecter la version ;
- propose un auto-incrément si nécessaire ;
- retourne le `md5`, la taille et l'origine de la version retenue.

`POST /api/fuota/releases/upload` :
- prépare le binaire ;
- publie le fichier dans `Vercel Blob`;
- enregistre la release en base.

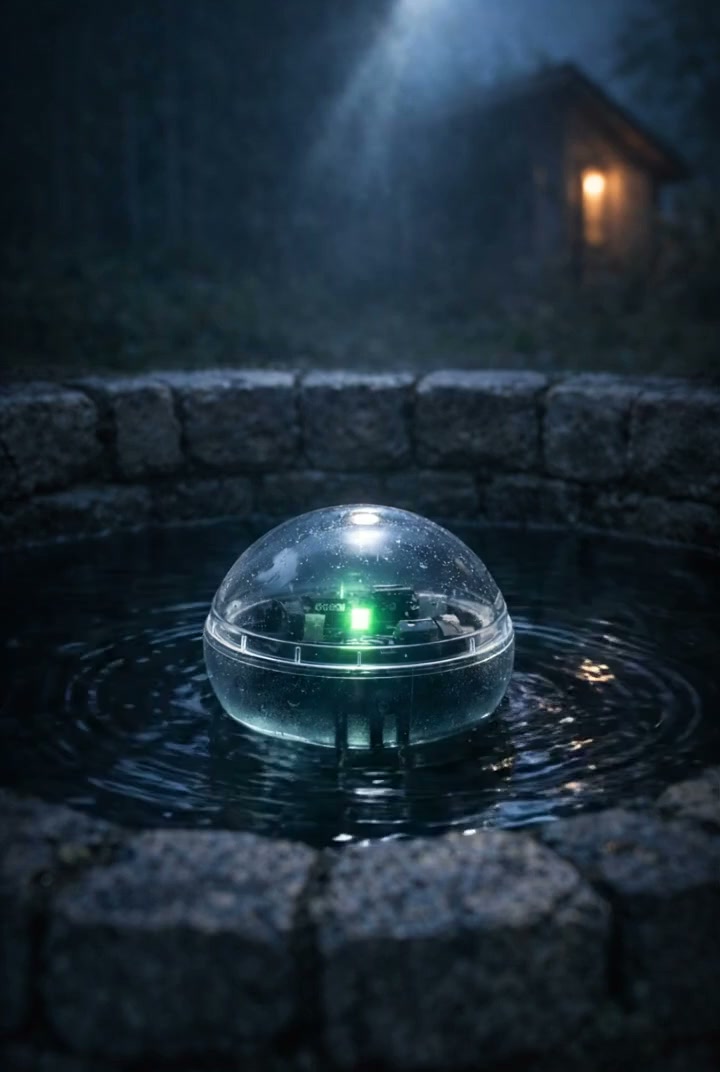
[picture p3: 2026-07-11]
EauSure_User_MobileApp/assets/onboarding/slide-frame-5.jpg

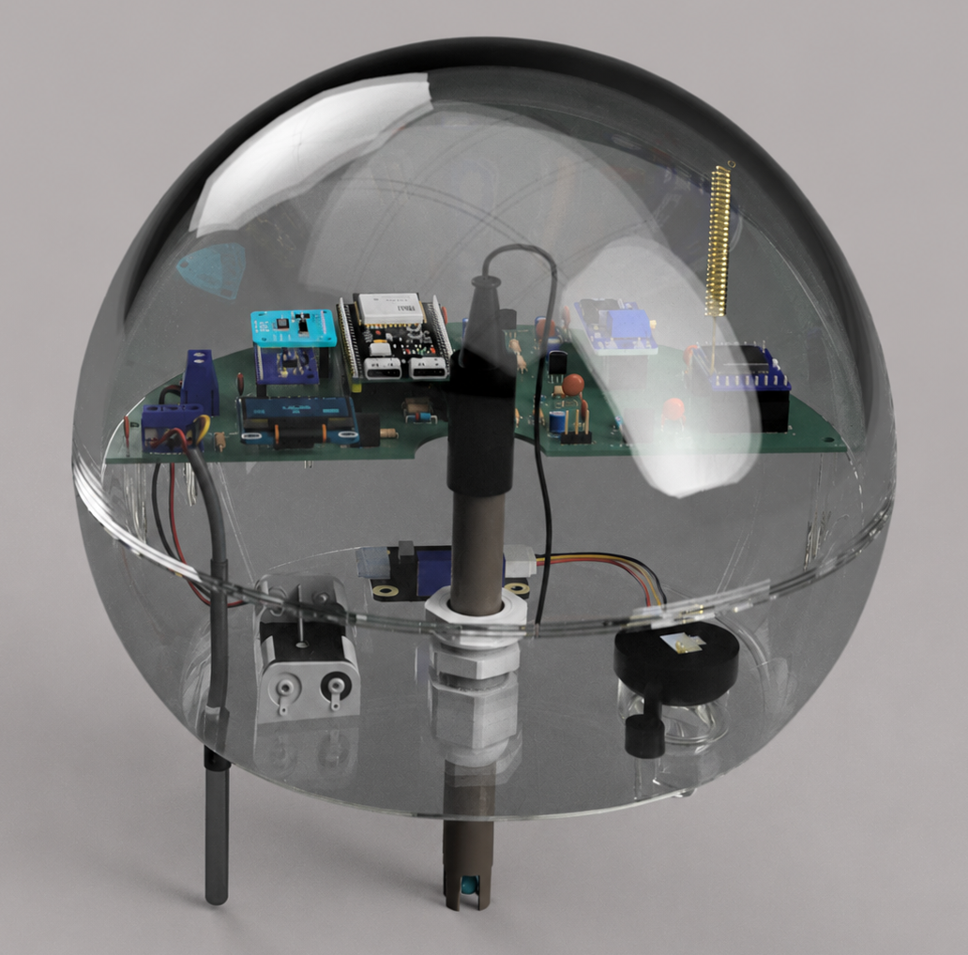
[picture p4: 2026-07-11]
EauSure_User_MobileApp/assets/branding/buoy-3d.png

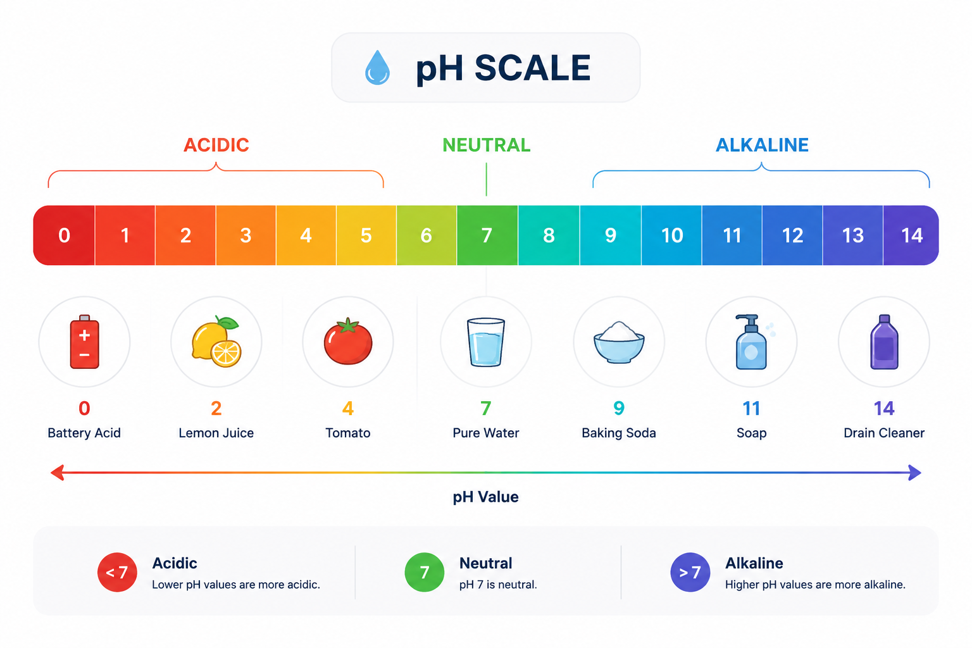
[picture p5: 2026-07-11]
EauSure_User_MobileApp/assets/illustrations/ph-scale.png

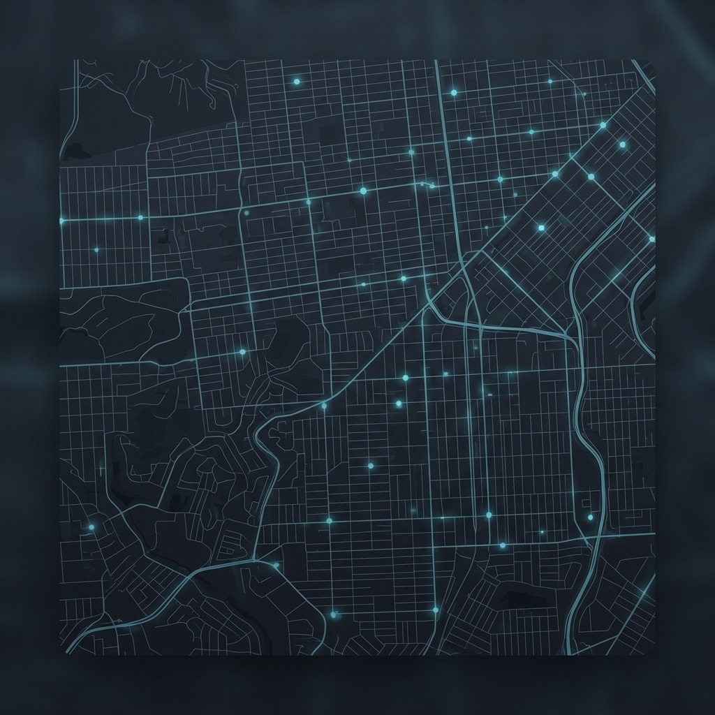
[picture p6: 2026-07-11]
EauSure_User_MobileApp/assets/illustrations/map-background.png

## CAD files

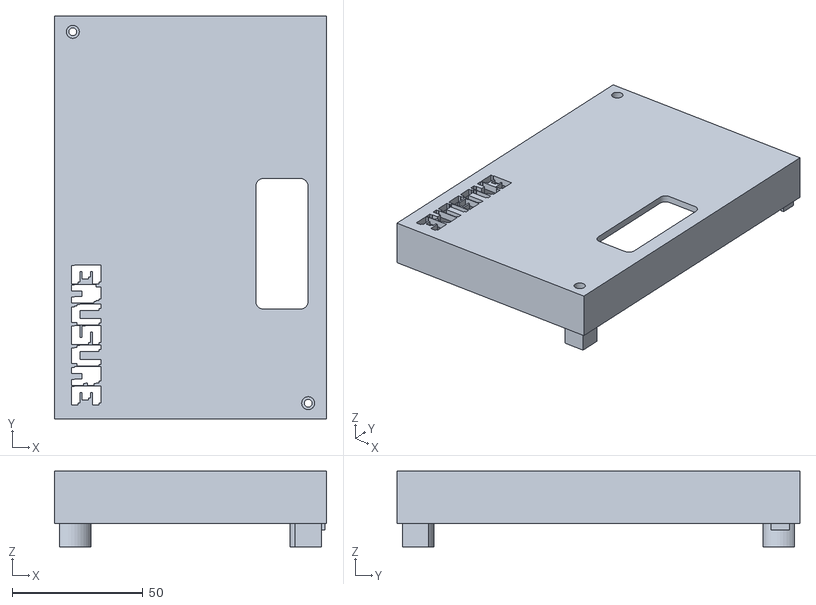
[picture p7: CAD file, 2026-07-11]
EauSure_3D/Gateway_Node/stl/gateway_up_shell.stl
104.0 x 154.0 x 29.0

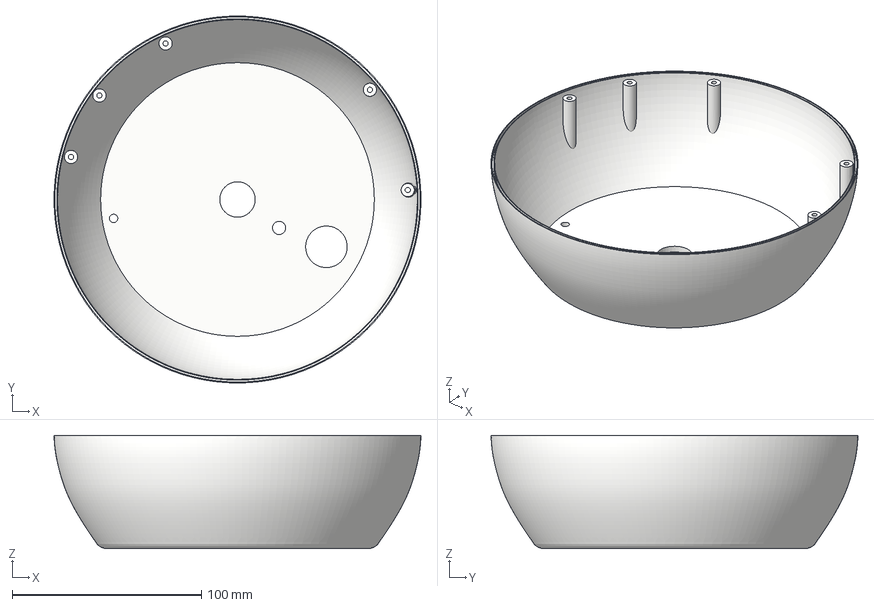
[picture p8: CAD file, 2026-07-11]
EauSure_3D/IoT_Node/source/eausure-buoy-lower-shell.3mf
194.0 x 194.0 x 59.8 mm

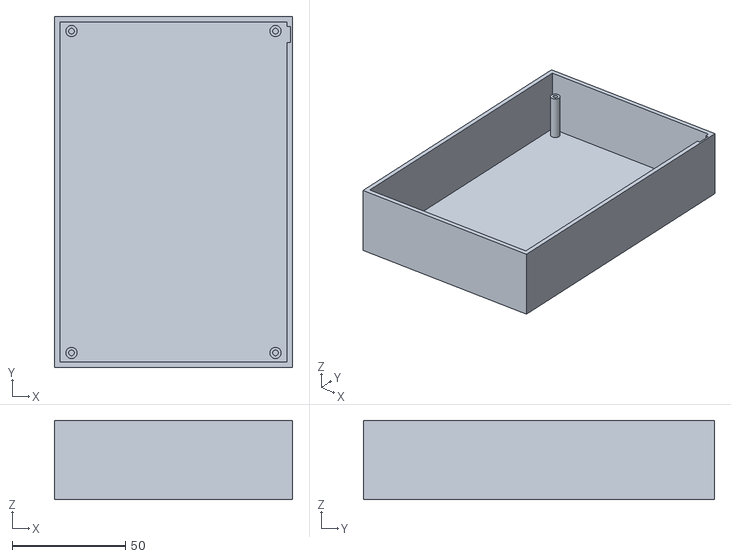
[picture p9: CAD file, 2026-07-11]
EauSure_3D/Gateway_Node/stl/gateway_low_shell.stl
105.0 x 155.0 x 35.0

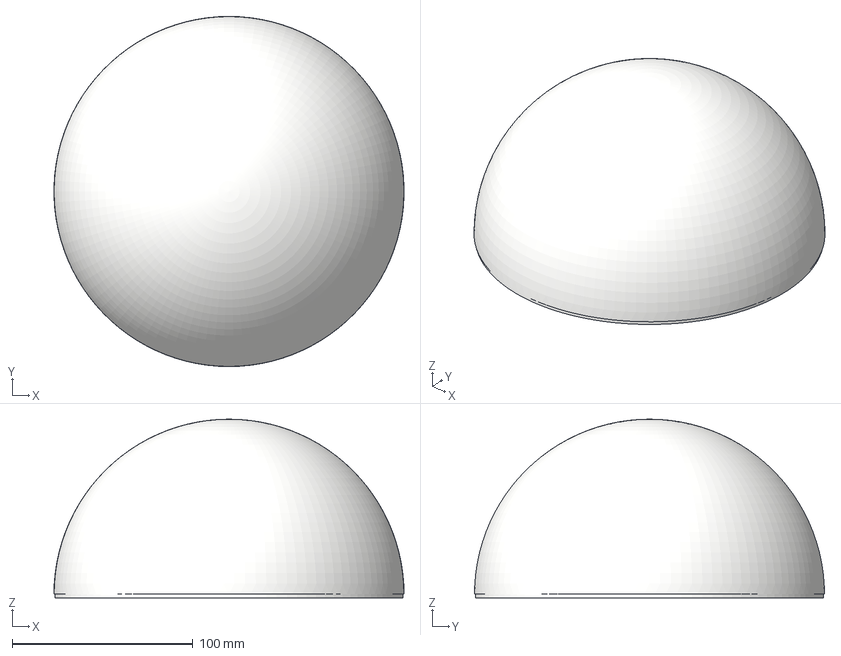
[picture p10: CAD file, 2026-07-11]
EauSure_3D/IoT_Node/source/eausure-buoy-upper-shell.3mf
193.9 x 194.0 x 99.0 mm

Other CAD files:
EauSure_3D/IoT_Node/exports/stl/eausure-buoy-lower-shell.stl
EauSure_3D/IoT_Node/exports/stl/eausure-buoy-upper-shell.stl

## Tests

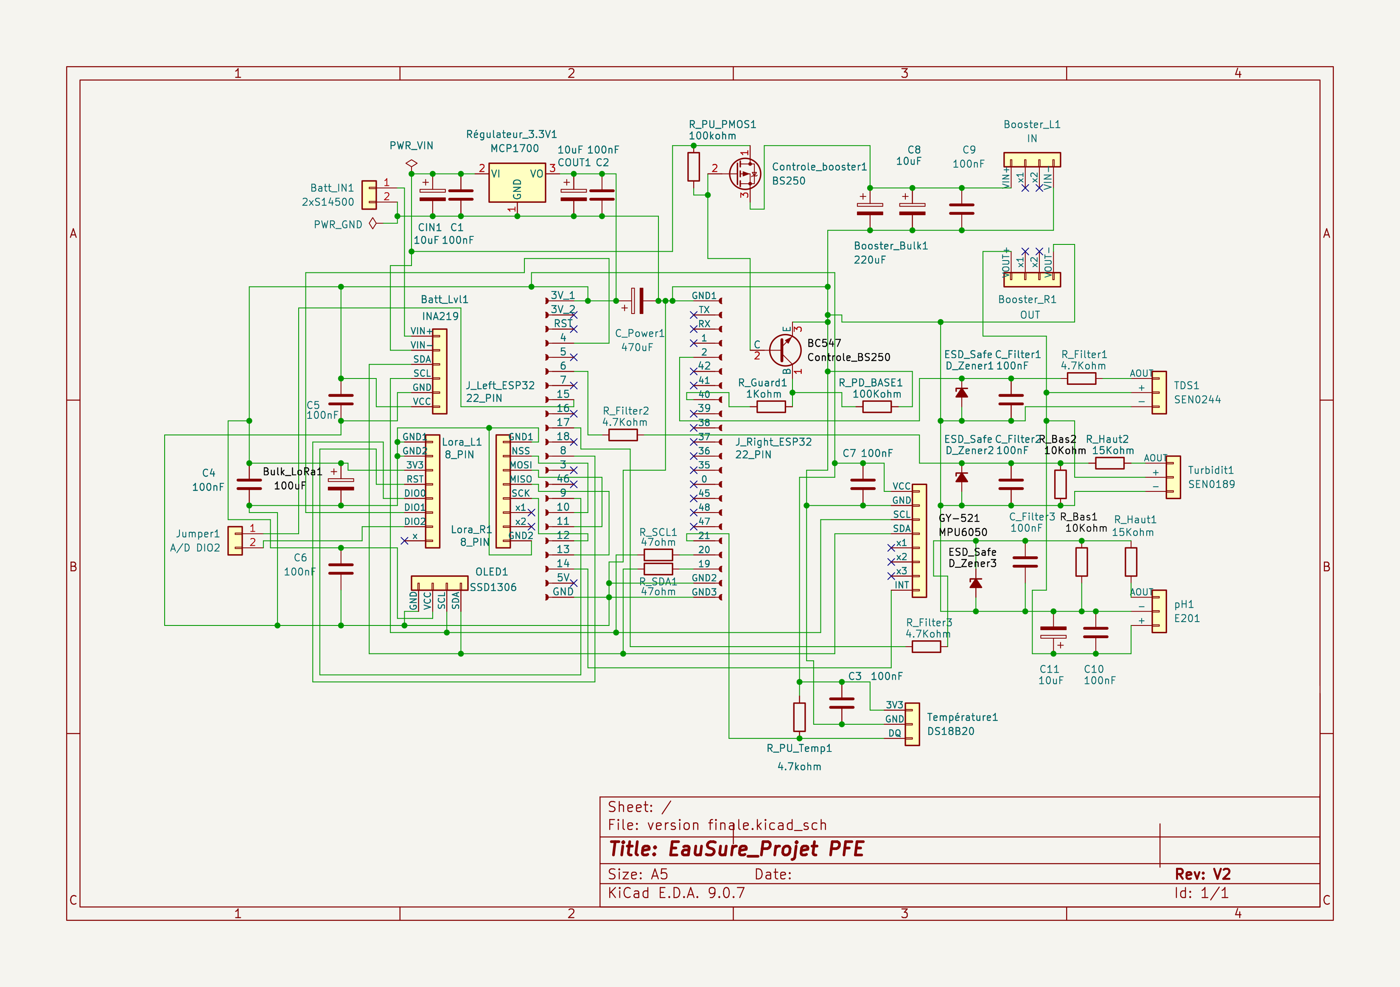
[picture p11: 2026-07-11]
EauSure_PCB/exports/schematics/eausure-measurement-node-full.png

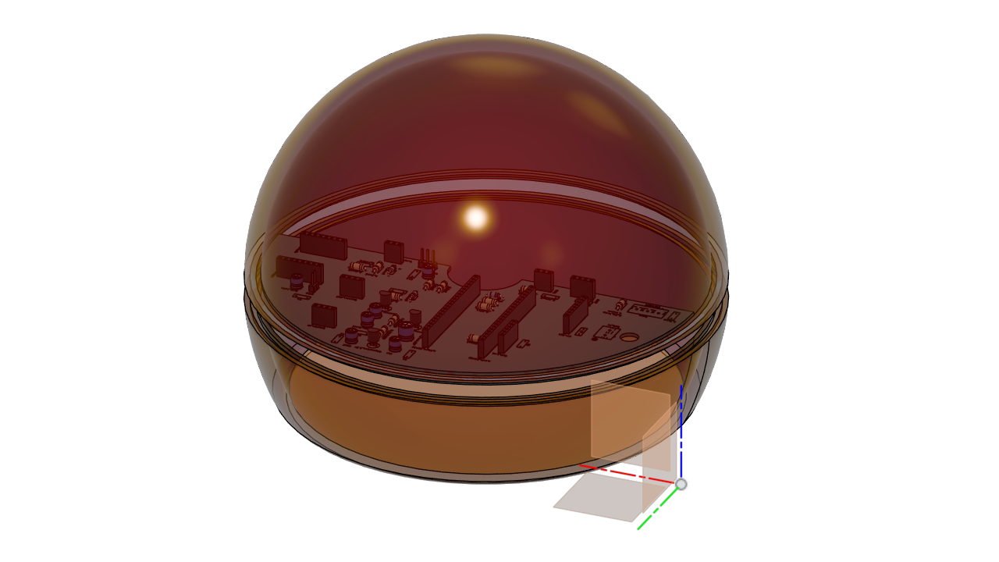
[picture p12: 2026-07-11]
EauSure_PCB/exports/board/eausure-measurement-node-board-view-with-enclosure.png

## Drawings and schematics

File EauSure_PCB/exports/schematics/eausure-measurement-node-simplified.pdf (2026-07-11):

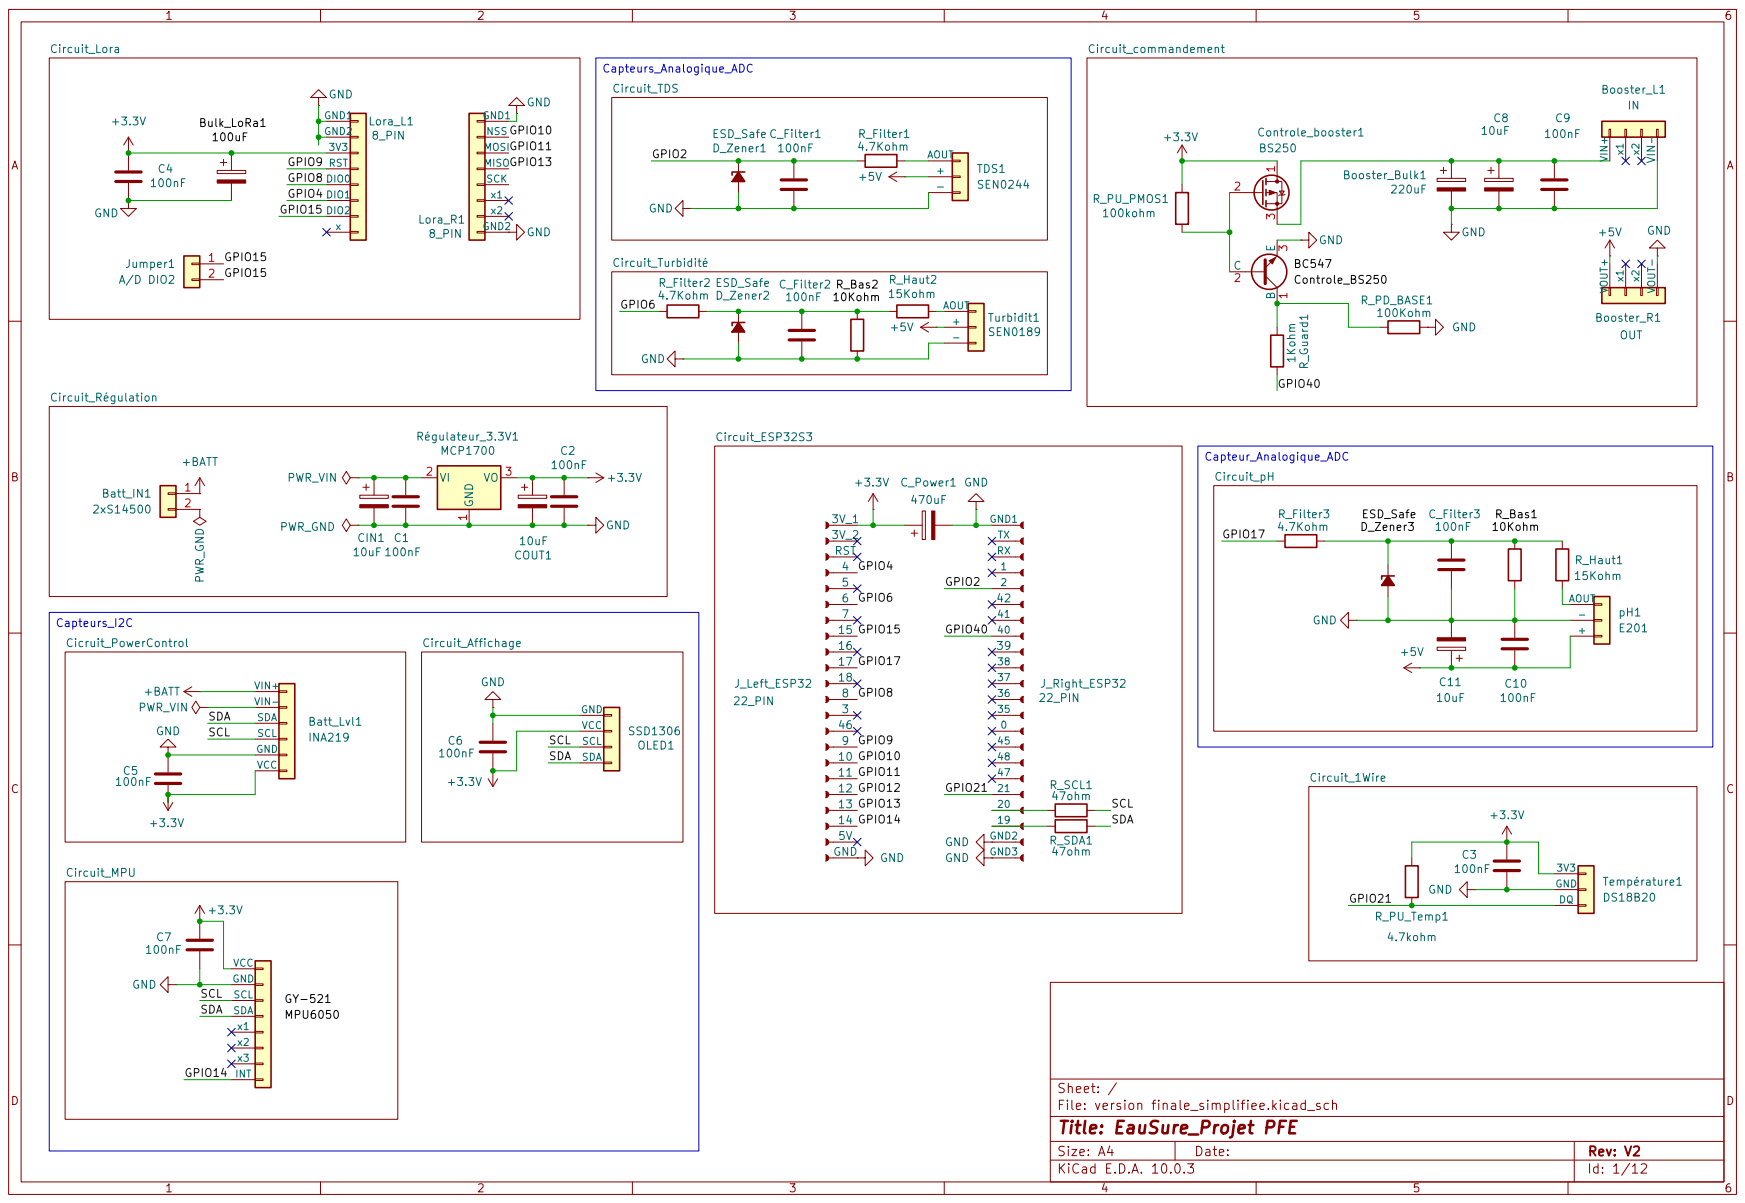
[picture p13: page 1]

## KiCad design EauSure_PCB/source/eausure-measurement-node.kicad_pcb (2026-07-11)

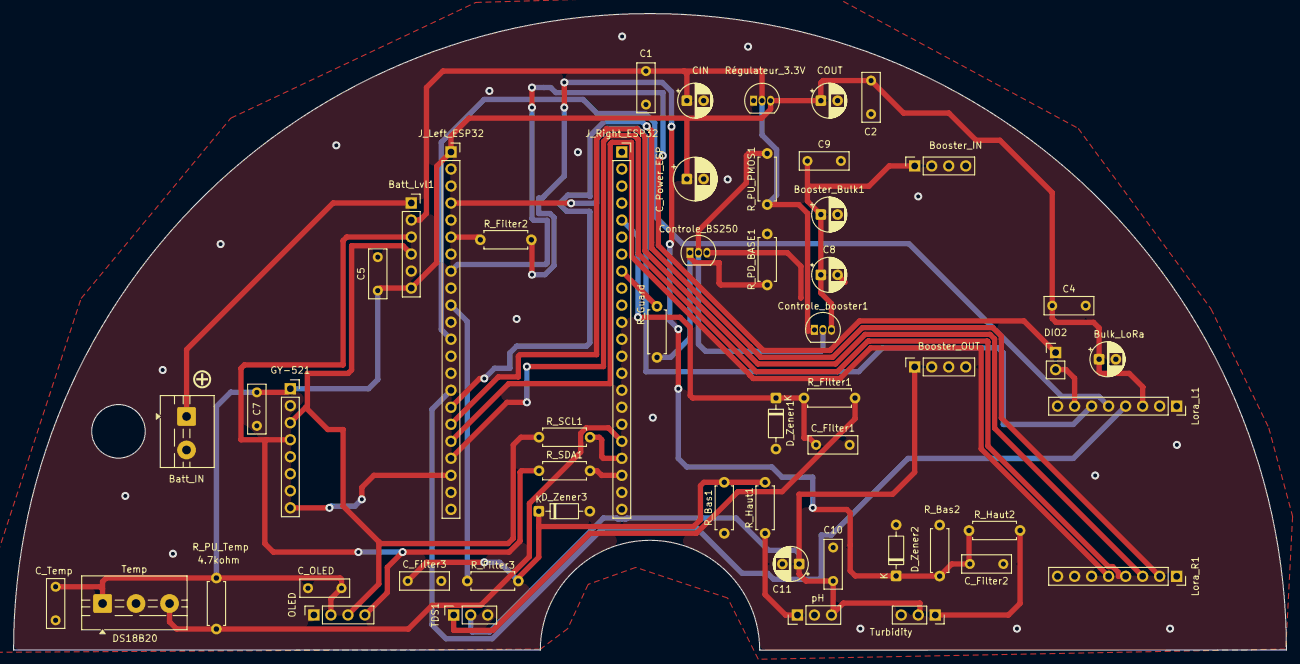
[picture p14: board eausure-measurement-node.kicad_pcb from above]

Board: 2 copper layers, 190.0 x 95.0 mm, 53 parts (0 on the bottom side), 32 nets.

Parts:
Batt_IN: 2xS14500; TerminalBlock_MaiXu_MX126-5.0-02P_1x02_P5.00mm
Batt_Lvl1: INA219; PinSocket_1x06_P2.54mm_Vertical
Booster_Bulk1: 220uF; CP_Radial_D5.0mm_P2.50mm
Booster_IN: IN; PinSocket_1x04_P2.54mm_Vertical
Booster_OUT: OUT; PinSocket_1x04_P2.54mm_Vertical
Bulk_LoRa: 100uF; CP_Radial_D5.0mm_P2.50mm
C1, C2, C4, C5, C7, C9, C10: 100nF; C_Rect_L7.2mm_W2.5mm_P5.00mm
C8, C11: 10uF; CP_Radial_D5.0mm_P2.50mm
CIN: 10uF; CP_Radial_D5.0mm_P2.50mm
COUT: 10uF; CP_Radial_D5.0mm_P2.50mm
C_Filter1, C_Filter2, C_Filter3: 100nF; C_Rect_L7.2mm_W2.5mm_P5.00mm
C_OLED: 100nF; C_Rect_L7.2mm_W2.5mm_P5.00mm
C_Power_ESP: 470uF; CP_Radial_D6.3mm_P2.50mm
C_Temp: 100nF; C_Rect_L7.2mm_W2.5mm_P5.00mm
Controle_BS250: BC547; TO-92_Inline
Controle_booster1: BS250; TO-92_Inline
DIO2: A/D DIO2; PinHeader_1x02_P2.54mm_Vertical
D_Zener1, D_Zener2, D_Zener3: ESD_Safe; D_DO-35_SOD27_P7.62mm_Horizontal
GY-521: MPU6050; PinSocket_1x08_P2.54mm_Vertical
J_Left_ESP32: 22_PIN; PinSocket_1x22_P2.54mm_Vertical
J_Right_ESP32: 22_PIN; PinSocket_1x22_P2.54mm_Vertical
Lora_L1: 8_PIN; PinSocket_1x08_P2.54mm_Vertical
Lora_R1: 8_PIN; PinSocket_1x08_P2.54mm_Vertical
OLED: SSD1306; PinSocket_1x04_P2.54mm_Vertical
R_Bas1, R_Bas2: 10Kohm; R_Axial_DIN0207_L6.3mm_D2.5mm_P7.62mm_Horizontal
R_Filter1, R_Filter2, R_Filter3: 4.7Kohm; R_Axial_DIN0207_L6.3mm_D2.5mm_P7.62mm_Horizontal
R_Guard: 1Kohm; R_Axial_DIN0207_L6.3mm_D2.5mm_P7.62mm_Horizontal
R_Haut1, R_Haut2: 15Kohm; R_Axial_DIN0207_L6.3mm_D2.5mm_P7.62mm_Horizontal
R_PD_BASE1: 100Kohm; R_Axial_DIN0207_L6.3mm_D2.5mm_P7.62mm_Horizontal
R_PU_PMOS1: 100kohm; R_Axial_DIN0207_L6.3mm_D2.5mm_P7.62mm_Horizontal
R_PU_Temp: 4.7kohm; R_Axial_DIN0207_L6.3mm_D2.5mm_P7.62mm_Horizontal
R_SCL1: 47ohm; R_Axial_DIN0207_L6.3mm_D2.5mm_P7.62mm_Horizontal
R_SDA1: 47ohm; R_Axial_DIN0207_L6.3mm_D2.5mm_P7.62mm_Horizontal
Régulateur_3.3V: MCP1700; TO-92_Inline
TDS1: SEN0244; PinSocket_1x03_P2.54mm_Vertical
Temp: DS18B20; TerminalBlock_MaiXu_MX126-5.0-03P_1x03_P5.00mm
Turbidity: SEN0189; PinSocket_1x03_P2.54mm_Vertical
pH: E201; PinHeader_1x03_P2.54mm_Vertical

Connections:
unnamed: Batt_IN.1, Batt_Lvl1.1 (VIN+)
unnamed: Batt_IN.2, Batt_Lvl1.5 (GND), Booster_Bulk1.2, Booster_IN.4 (VIN-), Booster_OUT.4 (VOUT-), Bulk_LoRa.2, C1.2, C2.2, C4.2, C5.2, C7.1, C8.2, C9.2, C10.1, C11.2, CIN.2, COUT.2, C_Filter1.2, C_Filter2.2, C_Filter3.2, C_OLED.2, C_Power_ESP.2, C_Temp.1, Controle_BS250.3 (E), D_Zener1.2 (A), D_Zener2.2 (A), D_Zener3.2 (A), GY-521.2 (GND), J_Left_ESP32.22 (GND), J_Right_ESP32.1 (GND1), J_Right_ESP32.21 (GND2), J_Right_ESP32.22 (GND3), Lora_L1.1 (GND1), Lora_L1.2 (GND2), Lora_R1.1 (GND1), Lora_R1.8 (GND2), OLED.1 (GND), R_Bas1.1, R_Bas2.1, R_PD_BASE1.2, Régulateur_3.3V.1 (GND), TDS1.3 (-), Temp.2 (GND), Turbidity.3 (-), pH.2 (-)
unnamed: Batt_Lvl1.4 (SCL), GY-521.3 (SCL), OLED.3 (SCL), R_SCL1.1
unnamed: Batt_Lvl1.3 (SDA), GY-521.4 (SDA), OLED.4 (SDA), R_SDA1.1
unnamed: Batt_Lvl1.6 (VCC), Bulk_LoRa.1, C2.1, C4.1, C5.1, C7.2, COUT.1, C_OLED.1, C_Power_ESP.1, C_Temp.2, GY-521.1 (VCC), J_Left_ESP32.1 (3V_1), Lora_L1.3 (3V3), OLED.2 (VCC), R_PU_Temp.2, Régulateur_3.3V.3 (VO), Temp.1 (3V3)
unnamed: Batt_Lvl1.2 (VIN-), C1.1, CIN.1, Controle_booster1.1 (S), R_PU_PMOS1.1, Régulateur_3.3V.2 (VI)
unnamed: Booster_Bulk1.1, Booster_IN.1 (VIN+), C8.1, C9.1, Controle_booster1.3 (D)
unnamed: Booster_OUT.1 (VOUT+), C10.2, C11.1, TDS1.2 (+), Turbidity.2 (+), pH.3 (+)
unnamed: Controle_BS250.1 (B), R_Guard.2, R_PD_BASE1.1
unnamed: Controle_BS250.2 (C), Controle_booster1.2 (G), R_PU_PMOS1.2
unnamed: C_Filter1.1, D_Zener1.1 (K), J_Right_ESP32.5 (2), R_Filter1.1
unnamed: C_Filter2.1, D_Zener2.1 (K), R_Bas2.2, R_Filter2.2, R_Haut2.1
unnamed: C_Filter3.1, D_Zener3.1 (K), R_Bas1.2, R_Filter3.2, R_Haut1.2
unnamed: GY-521.8 (INT), J_Left_ESP32.20 (14)
unnamed: J_Left_ESP32.12 (8), Lora_L1.5 (DIO0)
unnamed: J_Left_ESP32.15 (9), Lora_L1.4 (RST)
unnamed: J_Left_ESP32.16 (10), Lora_R1.2 (NSS)
unnamed: J_Left_ESP32.17 (11), Lora_R1.3 (MOSI)
unnamed: J_Left_ESP32.18 (12), Lora_R1.5 (SCK)
unnamed: J_Left_ESP32.19 (13), Lora_R1.4 (MISO)
unnamed: DIO2.1, J_Left_ESP32.8 (15)
unnamed: J_Left_ESP32.10 (17), R_Filter3.1
unnamed: J_Left_ESP32.6, R_Filter2.1
unnamed: J_Right_ESP32.20 (19), R_SDA1.2
unnamed: J_Right_ESP32.19 (20), R_SCL1.2
unnamed: J_Right_ESP32.18 (21), R_PU_Temp.1, Temp.3 (DQ)
unnamed: J_Right_ESP32.8 (40), R_Guard.1
unnamed: DIO2.2, Lora_L1.7 (DIO2)
unnamed: J_Left_ESP32.4, Lora_L1.6 (DIO1)
unnamed: R_Filter1.2, TDS1.1 (AOUT)
unnamed: R_Haut2.2, Turbidity.1 (AOUT)
unnamed: R_Haut1.1, pH.1 (AOUT)

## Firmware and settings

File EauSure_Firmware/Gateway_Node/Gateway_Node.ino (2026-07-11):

#include "wifi_store.h"
#include "provisioning_mode.h"
#include "normal_mode.h"
#include "node_pairing_mode.h"
#include "node_pairing_store.h"
#include "mqtt_gateway.h"
#include "otaa_manager.h"
#include "telemetry.h"
#include "hardware_ui.h"
#include "audio_alert.h"
#include "sd_logger.h"
#include "wifi_manager.h"
#include "fuota_manager.h"
#include <esp_bt.h>

enum class BootMode {
  PROVISIONING,
  NODE_PAIRING,
  NORMAL
};

static BootMode gMode = BootMode::PROVISIONING;
static String gLastPublishedCandidateId = "";

void setup() {
  esp_bt_controller_mem_release(ESP_BT_MODE_CLASSIC_BT);
  Serial.begin(115200);
  delay(300);

  HardwareUI::begin();
  WifiStore::begin();
  NodePairingStore::begin();
  FuotaManager::begin();

  // IMPORTANT: SD mount is deferred on purpose.
  //
  // Cold-boot rage case: on power-on the 3V3 rail is still settling while
  // LoRa + MAX98357A + ESP32 all draw their inrush, and a fresh MicroSD
  // needs ~1s of post-VCC idle before it reliably accepts CMD0. Mounting
  // here was failing on cold plug-in but working after a soft reset
  // because the rail was already stable.
  //
  // Every SD consumer (audio_alert, future FUOTA) already goes through
  // ensureSdReady(), which mounts on demand with backoff. By the time
  // the first demand happens (audio alert, factory-reset voice, OTA...)
  // the rail has been stable for many seconds and BLE/WiFi are quiet.
  Serial.println("[BOOT] SD mount deferred — will mount on first demand");

  if (!WifiStore::hasWifiCredentials()) {
    gMode = BootMode::PROVISIONING;
    Serial.println("[BOOT] No WiFi -> PROVISIONING mode");
    ProvisioningMode::begin();
    return;
  }

  if (!NodePairingStore::hasPairing()) {
    gMode = BootMode::NODE_PAIRING;
    Serial.println("[BOOT] No node pairing -> NODE_PAIRING mode");
    NodePairingMode::begin();
    MqttGateway::begin();
    return;
  }

  gMode = BootMode::NORMAL;
  Serial.println("[BOOT] Ready -> NORMAL mode");
  NormalMode::begin();
  MqttGateway::begin();
}

void loop() {
  switch (gMode) {

    case BootMode::PROVISIONING:
      ProvisioningMode::loop();

      if (ProvisioningMode::isComplete()) {
        Serial.println("[BOOT] Provisioning complete -> restarting...");
        delay(1000);
        ESP.restart();
      }
      break;

    case BootMode::NODE_PAIRING:
      if (!NodePairingMode::shouldPauseMqtt()) {
        MqttGateway::loop();
      }
      NodePairingMode::loop();

      if (NodePairingMode::hasCandidate()) {
        PairingCandidateInfo c = NodePairingMode::getCandidate();

        if (!c.nodeId.isEmpty() && c.nodeId != gLastPublishedCandidateId) {
          if (MqttGateway::publishCandidateFound(c.nodeId, c.nodeName, c.bleMac)) {
            gLastPublishedCandidateId = c.nodeId;
          }
        }
      } else if (!gLastPublishedCandidateId.isEmpty()) {
        // Allow the same nearby node to be re-published after retries/timeouts.
        gLastPublishedCandidateId = "";
      }

      if (NodePairingMode::isComplete()) {
        Serial.println("[BOOT] Node pairing complete -> restarting...");
        delay(1000);
        ESP.restart();
      }
      break;

    case BootMode::NORMAL:
      // Check if the UI task requested a factory reset while WiFi was up.
      // The UI task cannot safely make HTTPS calls (heap corruption with
      // concurrent TLS clients), so we handle it here in the main loop
      // context where MQTT is already managed.
      if (HardwareUI::isFactoryResetRequested()) {
        Serial.println("[BOOT] Factory reset requested — notifying backend from main loop");
        MqttGateway::setExclusiveTlsWindow(true);
        delay(100);
        WiFiManager::unprovisionGateway();
        delay(200);
        Serial.println("[BOOT] Unprovision done — rebooting");
        ESP.restart();
      }

      FuotaManager::loop();
      if (FuotaManager::isGatewayUpdateInProgress()) {
        delay(10);
        break;
      }
      if (!shouldPauseBackgroundWork() && !telemetryHasPendingUpload()) {
        MqttGateway::loop();
      }
      NormalMode::loop();
      break;
  }
}

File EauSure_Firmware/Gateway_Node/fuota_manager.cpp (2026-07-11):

#include "fuota_manager.h"

#include <SD.h>
#include <esp_system.h>
#include <ArduinoJson.h>

#include "audio_alert.h"
#include "fuota_job_store.h"
#include "lora_radio.h"
#include "mqtt_gateway.h"
#include "node_pairing_store.h"
#include "sd_logger.h"
#include "telemetry.h"
#include "wifi_manager.h"

namespace {

constexpr const char* kGatewayFwPath = "/fw/gateway_update.bin";
constexpr const char* kNodeFwPath    = "/fw/node_update.bin";
constexpr uint16_t    kFuotaChunkSize = 160;
constexpr uint32_t    kTransferRetryMinGapMs = 60000;
constexpr uint32_t    kMaxTransferAttempts = 40;

enum class UpdateTarget {
  None,
  Gateway,
  Node,
};

enum class UpdateState {
  Idle,
  DownloadPending,
  Downloaded,
  Failed,
};

struct PendingUpdate {
  UpdateTarget target = UpdateTarget::None;
  UpdateState state = UpdateState::Idle;
  String cmdId;
  String nodeId;
  String url;
  String version;
  String md5;
  size_t size = 0;
  String sdPath;
  uint32_t sessionId = 0;
  uint32_t transferAttempts = 0;
  uint32_t lastTransferAttemptMs = 0;
  String error;
};

PendingUpdate gPendingUpdate;
bool gBusy = false;
bool gCommandAcked = false;
bool gCommandFailed = false;

void publishFuotaPhase(const char* phase, const char* message = "") {
  StaticJsonDocument<384> doc;
  doc["phase"] = phase;
  doc["target"] = (gPendingUpdate.target == UpdateTarget::Gateway) ? "gateway" : "node";
  if (!gPendingUpdate.nodeId.isEmpty()) {
    doc["nodeId"] = gPendingUpdate.nodeId;
  }
  if (!gPendingUpdate.version.isEmpty()) {
    doc["version"] = gPendingUpdate.version;
  }
  if (!gPendingUpdate.cmdId.isEmpty()) {
    doc["cmdId"] = gPendingUpdate.cmdId;
  }
  if (message && message[0] != '\0') {
    doc["message"] = message;
  }
  doc["attempt"] = gPendingUpdate.transferAttempts;

  String payload;
  serializeJson(doc, payload);
  MqttGateway::publishEvent("fuota_progress", payload);
}

void persistJob() {
  if (gPendingUpdate.target == UpdateTarget::None) {
    FuotaJobStore::clear();
    return;
  }

  FuotaJobStore::StoredJob job;
  job.valid = true;
  job.target = (gPendingUpdate.target == UpdateTarget::Gateway)
                   ? FuotaJobStore::StoredTarget::Gateway
                   : FuotaJobStore::StoredTarget::Node;
  switch (gPendingUpdate.state) {
    case UpdateState::DownloadPending:
      job.state = FuotaJobStore::StoredState::DownloadPending;
      break;
    case UpdateState::Downloaded:
      job.state = FuotaJobStore::StoredState::Downloaded;
      break;
    case UpdateState::Failed:
      job.state = FuotaJobStore::StoredState::Failed;
      break;
    default:
      job.state = FuotaJobStore::StoredState::Idle;
      break;
  }
  job.cmdId = gPendingUpdate.cmdId;
  job.nodeId = gPendingUpdate.nodeId;
  job.url = gPendingUpdate.url;
  job.version = gPendingUpdate.version;
  job.md5 = gPendingUpdate.md5;
  job.size = gPendingUpdate.size;
  job.sdPath = gPendingUpdate.sdPath;
  job.sessionId = gPendingUpdate.sessionId;
  job.transferAttempts = gPendingUpdate.transferAttempts;
  job.lastTransferAttemptMs = gPendingUpdate.lastTransferAttemptMs;
  job.error = gPendingUpdate.error;
  FuotaJobStore::save(job);
}

bool ensureFirmwareDirectory() {
  if (!ensureSdReady()) {
    return false;
  }

  if (SD.exists("/fw")) {
    return true;
  }

  return SD.mkdir("/fw");
}

void clearPendingUpdate() {
  gPendingUpdate = PendingUpdate{};
  gBusy = false;
  FuotaJobStore::clear();
}

void markFailed(const String& reason) {
  gPendingUpdate.state = UpdateState::Failed;
  gPendingUpdate.error = reason;
  gCommandFailed = true;
  persistJob();
  publishFuotaPhase("failed", reason.c_str());
  Serial.printf("[FUOTA] Job failed: %s\n", reason.c_str());
}

bool restoreFromStore() {
  FuotaJobStore::StoredJob job;
  if (!FuotaJobStore::load(job)) {
    return false;
  }

  gPendingUpdate = PendingUpdate{};
  gPendingUpdate.target = (job.target == FuotaJobStore::StoredTarget::Gateway)
                              ? UpdateTarget::Gateway
                              : UpdateTarget::Node;
  switch (job.state) {
    case FuotaJobStore::StoredState::DownloadPending:
      gPendingUpdate.state = UpdateState::DownloadPending;
      break;
    case FuotaJobStore::StoredState::Downloaded:
      gPendingUpdate.state = UpdateState::Downloaded;
      break;
    case FuotaJobStore::StoredState::Failed:
      gPendingUpdate.state = UpdateState::Failed;
      gCommandFailed = true;
      break;
    default:
      return false;
  }

  gPendingUpdate.cmdId = job.cmdId;
  gPendingUpdate.nodeId = job.nodeId;
  gPendingUpdate.url = job.url;
  gPendingUpdate.version = job.version;
  gPendingUpdate.md5 = job.md5;
  gPendingUpdate.size = job.size;
  gPendingUpdate.sdPath = job.sdPath;
  gPendingUpdate.sessionId = job.sessionId;
  gPendingUpdate.transferAttempts = job.transferAttempts;
  gPendingUpdate.lastTransferAttemptMs = job.lastTransferAttemptMs;
  gPendingUpdate.error = job.error;

  Serial.printf("[FUOTA] Restored job target=%d state=%d version=%s attempts=%lu\n",
                (int)gPendingUpdate.target,
                (int)gPendingUpdate.state,
                gPendingUpdate.version.c_str(),
                (unsigned long)gPendingUpdate.transferAttempts);
  return true;
}

bool downloadPendingUpdate() {
  if (gPendingUpdate.state != UpdateState::DownloadPending) {
    return false;
  }

  publishFuotaPhase("downloading");

  if (!ensureFirmwareDirectory()) {
    markFailed("SD not ready");
    return false;
  }

  String error;
  if (!WiFiManager::downloadFileToSd(gPendingUpdate.url, gPendingUpdate.sdPath.c_str(),
                                     gPendingUpdate.size, &error)) {
    markFailed(error.isEmpty() ? "Download failed" : error);
    return false;
  }

  gPendingUpdate.state = UpdateState::Downloaded;
  gPendingUpdate.error = "";
  persistJob();
  // Acknowledge the MQTT command once the image is on SD (LoRa transfer may still be pending for nodes).
  if (!gPendingUpdate.cmdId.isEmpty()) {
    gCommandAcked = true;
  }
  publishFuotaPhase("downloaded", "Firmware on SD — waiting for apply window");
  Serial.printf("[FUOTA] Download complete for target=%d version=%s path=%s\n",
                (int)gPendingUpdate.target,
                gPendingUpdate.version.c_str(),
                gPendingUpdate.sdPath.c_str());
  return true;
}

bool applyGatewayUpdateNow() {
  String error;
  gBusy = true;
  stopAlarm();
  publishFuotaPhase("applying", "Gateway OTA apply");
  MqttGateway::setExclusiveTlsWindow(true);
  const bool ok = applyFirmwareFromSd(gPendingUpdate.sdPath.c_str(), gPendingUpdate.md5.c_str(), &error);
  MqttGateway::setExclusiveTlsWindow(false);
  gBusy = false;

  if (!ok) {
    markFailed(error.isEmpty() ? "Gateway OTA failed" : error);
    return false;
  }

  publishFuotaPhase("succeeded", "Gateway rebooting with new firmware");
  gCommandAcked = true;
  clearPendingUpdate();
  return true;
}
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

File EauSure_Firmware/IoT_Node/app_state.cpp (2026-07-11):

#include "app_state.h"
#include "lora_radio.h"
#include "display_oled.h"
#include "pairing_store.h"

// =====================================================
// Global device instances
// =====================================================
Adafruit_SSD1306   display(SCREEN_WIDTH, SCREEN_HEIGHT, &Wire, -1);
Adafruit_INA219    ina219;
bool               inaOk = false;

OneWire            oneWire(ONE_WIRE_BUS);
DallasTemperature  sensors(&oneWire);

bool               mpuOk = false;

Adafruit_NeoPixel  pixel(RGB_COUNT, RGB_PIN, NEO_GRB + NEO_KHZ800);
bool               rgbActive = false;
uint32_t           rgbOffAt  = 0;

PendingShake gPendingShake;

// =====================================================
// Shared state
// =====================================================
SensorData     gSensorData;
EventState     gEventState;
RTC_DATA_ATTR volatile bool gNodeActive = false;   // false until Gateway sends ACTIVATE

float phVoltageAtNeutral = PH_VOLTAGE_AT_NEUTRAL;
float phSlope            = PH_SLOPE;

// Runtime config — defaults from config.h, overridable via SET_CONFIG
RTC_DATA_ATTR float    gRuntimeShakeThresholdG   = SHAKE_THRESHOLD_G;
RTC_DATA_ATTR bool     gRuntimeShakeEnabled      = true;

// =====================================================
// FreeRTOS primitives
// =====================================================
SemaphoreHandle_t gDataMutex      = nullptr;
SemaphoreHandle_t gI2CMutex       = nullptr;
SemaphoreHandle_t gLoRaMutex      = nullptr;
TaskHandle_t      gSensorTaskHandle = nullptr;


volatile bool gAckWaitActive = false;

// =====================================================
// Sequence counters
//   gTxSeq     — IoT outgoing frame counter (DATA / ACTIVATE_OK / HEARTBEAT_ACK)
//   gCtrlRxSeq — last accepted incoming command seq (replay protection)
// =====================================================
RTC_DATA_ATTR uint32_t gTxSeq     = 1;
RTC_DATA_ATTR uint32_t gCtrlRxSeq = 0;


uint8_t gRuntimeEncKey[16] = {0};
bool    gRuntimeEncKeyLoaded = false;

// =====================================================
// Binary encoding helpers
// =====================================================
void writeU16BE(uint8_t *dst, uint16_t v) {
  dst[0] = (uint8_t)((v >> 8) & 0xFF);
  dst[1] = (uint8_t)(v & 0xFF);
}

void writeU32BE(uint8_t *dst, uint32_t v) {
  dst[0] = (uint8_t)((v >> 24) & 0xFF);
  dst[1] = (uint8_t)((v >> 16) & 0xFF);
  dst[2] = (uint8_t)((v >> 8) & 0xFF);
  dst[3] = (uint8_t)(v & 0xFF);
}

uint16_t readU16BE(const uint8_t *src) {
  return (uint16_t)(((uint16_t)src[0] << 8) | src[1]);
}

uint32_t readU32BE(const uint8_t *src) {
  return ((uint32_t)src[0] << 24) |
         ((uint32_t)src[1] << 16) |
         ((uint32_t)src[2] << 8)  |
         ((uint32_t)src[3]);
}

// =====================================================
// CRC-16 CCITT
// =====================================================
uint16_t crc16Ccitt(const uint8_t *data, size_t len) {
  uint16_t crc = 0xFFFF;
  for (size_t i = 0; i < len; ++i) {
    crc ^= (uint16_t)data[i] << 8;
    for (uint8_t b = 0; b < 8; ++b) {
      if (crc & 0x8000) crc = (crc << 1) ^ 0x1021;
      else              crc = (crc << 1);
    }
  }
  return crc;
}


bool parseHexKey16(const String& hex, uint8_t out[16]) {
  if (hex.length() != 32) return false;

  for (int i = 0; i < 16; i++) {
    char hi = hex[i * 2];
    char lo = hex[i * 2 + 1];

    auto hexVal = [](char c) -> int {
      if (c >= '0' && c <= '9') return c - '0';
      if (c >= 'a' && c <= 'f') return 10 + (c - 'a');
      if (c >= 'A' && c <= 'F') return 10 + (c - 'A');
      return -1;
    };

    int h = hexVal(hi);
    int l = hexVal(lo);
    if (h < 0 || l < 0) return false;

    out[i] = (uint8_t)((h << 4) | l);
  }

  return true;
}

bool loadRuntimeEncKey() {
  NodePairingData p = PairingStore::load();
  if (!p.valid) {
    Serial.println("[KEY] No valid pairing found");
    gRuntimeEncKeyLoaded = false;
    return false;
  }

  if (!parseHexKey16(p.aesKeyHex, gRuntimeEncKey)) {
    Serial.println("[KEY] Invalid AES key in pairing store");
    gRuntimeEncKeyLoaded = false;
    return false;
  }

  gRuntimeEncKeyLoaded = true;
  Serial.println("[KEY] Runtime AES key loaded from pairing store");
  return true;
}

// =====================================================
// Build Nonce for GCM
// =====================================================
void buildNonce(uint32_t seq, uint8_t nonce[GCM_NONCE_LEN]) {
  writeU32BE(&nonce[0], DEVICE_ID);
  writeU32BE(&nonce[4], seq);
  nonce[8]  = random(0, 256);
  nonce[9]  = random(0, 256);
  nonce[10] = random(0, 256);
  nonce[11] = random(0, 256);
}

// =====================================================
// AES-GCM Decryption
// =====================================================
bool aesgcmDecrypt(
  const uint8_t *cipher,
  size_t cipherLen,
  const uint8_t nonce[GCM_NONCE_LEN],
  const uint8_t *aad,
  size_t aadLen,
  const uint8_t tag[GCM_TAG_LEN],
  uint8_t *plain
) {
  mbedtls_gcm_context gcm;
  mbedtls_gcm_init(&gcm);

  if (!gRuntimeEncKeyLoaded) {
    mbedtls_gcm_free(&gcm);
    return false;
  }

  if (mbedtls_gcm_setkey(&gcm, MBEDTLS_CIPHER_ID_AES, gRuntimeEncKey, 128) != 0) {
    mbedtls_gcm_free(&gcm);
    return false;
  }

  int rc = mbedtls_gcm_auth_decrypt(
    &gcm,
    cipherLen,
    nonce, GCM_NONCE_LEN,
    aad, aadLen,
    tag, GCM_TAG_LEN,
    cipher,
    plain
  );

  mbedtls_gcm_free(&gcm);
  return rc == 0;
}
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

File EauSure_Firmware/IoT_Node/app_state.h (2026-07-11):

#pragma once

#include <Arduino.h>
#include "config.h"
#include <Wire.h>
#include <SPI.h>
#include <LoRa.h>
#include <Adafruit_GFX.h>
#include <Adafruit_SSD1306.h>
#include <Adafruit_NeoPixel.h>
#include <Adafruit_INA219.h>
#include <ArduinoJson.h>
#include <OneWire.h>
#include <DallasTemperature.h>
#include <math.h>
#include "mbedtls/gcm.h"

#include "freertos/FreeRTOS.h"
#include "freertos/semphr.h"
#include "freertos/task.h"

// =====================================================
// Protocol MSG_TYPE constants  (shared with Gateway)
//
//  0x01  DATA         IoT → GW   MEASURE_RESP or SHAKE_ALERT
//  0x02  ACK          both dirs  transport acknowledgement
//  0x03  MEASURE_REQ  GW  → IoT  request a fresh sensor reading
//  0x04  HEARTBEAT_REQ GW → IoT  lightweight liveness ping
//  0x05  HEARTBEAT_ACK IoT → GW  liveness reply {batt%, state}
//  0x06  ACTIVATE     GW  → IoT  boot handshake — activate node
//  0x07  ACTIVATE_OK  IoT → GW   handshake reply {state, mac}
// =====================================================
static const uint8_t MSG_TYPE_DATA          = 0x01;
static const uint8_t MSG_TYPE_ACK           = 0x02;
static const uint8_t MSG_TYPE_MEASURE_REQ   = 0x03;
static const uint8_t MSG_TYPE_HEARTBEAT_REQ = 0x04;
static const uint8_t MSG_TYPE_HEARTBEAT_ACK = 0x05;
static const uint8_t MSG_TYPE_ACTIVATE      = 0x06;
static const uint8_t MSG_TYPE_ACTIVATE_OK   = 0x07;
static const uint8_t MSG_TYPE_SET_CONFIG    = 0x08;  // GW → IoT  push config update
static const uint8_t MSG_TYPE_UNPAIR        = 0x09;  // GW → IoT  dissociate node
static const uint8_t MSG_TYPE_SLEEP         = 0x0A;  // GW → IoT  command to deep sleep
static const uint8_t MSG_TYPE_FUOTA_BEGIN   = 0x0B;  // GW → IoT  start firmware transfer session
static const uint8_t MSG_TYPE_FUOTA_CHUNK   = 0x0C;  // GW → IoT  firmware chunk
static const uint8_t MSG_TYPE_FUOTA_END     = 0x0D;  // GW → IoT  end transfer and validate
static const uint8_t MSG_TYPE_FUOTA_COMMIT  = 0x0E;  // GW → IoT  apply received firmware

// =====================================================
// Frame layout constants
// =====================================================
static const size_t GCM_NONCE_LEN = 12;
static const size_t GCM_TAG_LEN   = 16;
static const size_t CRC_LEN       = 2;
// Header: [ver(1) | type(1) | deviceId(4) | seq(4) | nonce(12) | plainLen(2)] = 24 bytes
static const size_t HEADER_LEN    = 1 + 1 + 4 + 4 + GCM_NONCE_LEN + 2;
static const size_t MAX_PLAIN_LEN = 180;
static const size_t MAX_FRAME_LEN = HEADER_LEN + MAX_PLAIN_LEN + GCM_TAG_LEN + CRC_LEN;


// =====================================================
// OLED
// =====================================================
#define SCREEN_WIDTH  128
#define SCREEN_HEIGHT 64
#define OLED_ADDR     0x3C
#define I2C_SDA       19
#define I2C_SCL       20

// =====================================================
// INA219
// =====================================================
extern Adafruit_INA219 ina219;
extern bool inaOk;

// =====================================================
// DS18B20
// =====================================================
extern OneWire oneWire;
extern DallasTemperature sensors;

// =====================================================
// MPU6050
// =====================================================
extern bool mpuOk;

// =====================================================
// RGB NeoPixel
// =====================================================
extern Adafruit_NeoPixel pixel;
extern bool rgbActive;
extern uint32_t rgbOffAt;

// =====================================================
// Sequence counters
//   gTxSeq     — incremented for every DATA / ACK_OK frame IoT sends
//   gCtrlRxSeq — last accepted sequence from Gateway commands
//                used for replay protection on incoming frames
// =====================================================
extern uint32_t gTxSeq;
extern uint32_t gCtrlRxSeq;
extern volatile bool gAckWaitActive;

// =====================================================
// Shared sensor data
// =====================================================
struct SensorData {
  float waterTempC  = 25.0f;
  float mpuTempC    = 0.0f;
  float espTempC    = 0.0f;

  float battBusV      = 0.0f;
  float battShuntmV   = 0.0f;
  float battCurrentmA = 0.0f;
  float battPowermW   = 0.0f;
  float battLoadV     = 0.0f;
  int   battPercent   = 0;

  float lastTurbSensorVoltage = 0.0f;
  int   turbScale10           = 0;

  float lastTdsValue = 0.0f;
  int   tdsScale10   = 0;

  float lastPhVoltage = 0.0f;
  float lastPhValue   = 7.0f;
  int   phScale10     = 0;
};

struct EventState {
  uint32_t lastShakeAt      = 0;
  String   lastEvent        = "None";
  bool     isExploding      = false;
  uint32_t explosionStartAt = 0;
  // True while ControlTask is waiting for sensor task to finish —
  // MPU shake TX checks this to avoid stomping an in-progress read.
  bool     measureInProgress = false;
};

extern SensorData      gSensorData;
extern EventState      gEventState;
extern volatile bool   gNodeActive;

extern float phVoltageAtNeutral;
extern float phSlope;

// =====================================================
// Runtime config (updated via SET_CONFIG from gateway)
// =====================================================
extern float    gRuntimeShakeThresholdG;
extern bool     gRuntimeShakeEnabled;

// =====================================================
// Global devices
// =====================================================
extern Adafruit_SSD1306 display;

// =====================================================
// FreeRTOS primitives
// =====================================================
extern SemaphoreHandle_t gDataMutex;
extern SemaphoreHandle_t gI2CMutex;
extern SemaphoreHandle_t gLoRaMutex;

// Handle of the SensorTask — ControlTask sends TaskNotifications to it
extern TaskHandle_t gSensorTaskHandle;

// =====================================================
// App init
// =====================================================
bool initApp();

// =====================================================
// Low-level I2C / MPU
// =====================================================
bool i2cWrite8(uint8_t addr, uint8_t reg, uint8_t val);
bool i2cReadN(uint8_t addr, uint8_t startReg, uint8_t *buf, size_t n);
bool mpuInit();
void readMpuTemp();

// =====================================================
// RGB
// =====================================================
void rgbInit();
void rgbFlash(uint8_t r, uint8_t g, uint8_t b, uint32_t ms);
void updateRgb();

// =====================================================
// Battery
// =====================================================
void updateIna219();
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
